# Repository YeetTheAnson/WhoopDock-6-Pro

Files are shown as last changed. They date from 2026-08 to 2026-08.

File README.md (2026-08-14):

# WhoopDock 6 Pro

## Introduction

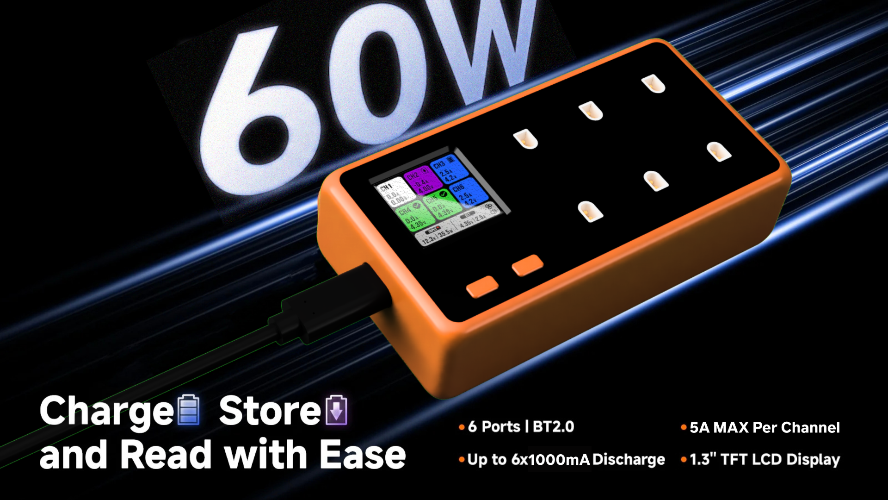
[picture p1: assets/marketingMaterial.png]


*Up to 130W when powered with VBUS pads

This is my custom BT2.0 battery charger! I started this project because I wanted a programmable 1S LiPo/LiHV multi channel charger that included discharging and storage mode. Commercial chargers like the hexachargers or whoopstor has all the mentioned features but it's limited and lack customizability.

This charger is designed primarily for tinywhoop FPV drone batteries that uses the BetaFPV BT2.0 connector, but its 5A charge current also allows it to be used with larger cylindrical cell batteries for long range drones.

| Feature | WhoopDock 6 Pro | BetaFPV Hexacharger | ViFly WhoopStor V3 |
| --- | --- | --- | --- |
| **Max Charge Current (Per Channel)** | **Up to 5A**  | 3.0A | 1.3A |
| **Max Discharge Current (Per Channel)** | **1.16A** | 0.4A | 0.3A |
| **Custom Discharge Current** | **Yes**  | No | No |
| **Target Voltage Control** | **Fully Customizable** | Presets Only | Presets Only |
| **Voltage Increments** | **16mV** | None (3.85V/4.2V/4.35V) | None (3.8V/3.85V/4.2V/4.35V) |
| **Current Increments** | **64mA** | 500mA | 100mA |
| **Big Colour Screen** | **Yes** | **Yes** | No |
| **Programmability** | **Yes** (Arduino compatible) | No (Closed source) | No (Closed source) |
| **WiFi & Bluetooth** | **Yes** | No | No |
| **Audio Feedback** | **Yes** | **Yes** | **Yes** |
| **Active Cooling** | **Yes** (Programmable fan curve) | **Yes** | **Yes** |
| **Reverse Polarity Protection** | **Yes** | No | **Yes** |

If you don't like how it works, you could always program it to replicate the behavior of your favorite charger.

### Advantages:

* **Current Delivery:** The WhoopDock is much more powerful compared to commercial chargers from BetaFPV and ViFly. With the BQ25890, you can charge large batteries up to 5A, or use the small 64mA interval to precisely control the charge current of small batteries. The 1.16A discharge rate means your large batteries will hit storage voltage way faster, and can be adjusted lower for smaller batteries.
* **Fine Control:** Instead of being forced to choose from specific presets, the 16mV step resolution allows you to charge different battery chemistries or set a custom charge termination voltage.
* **Connectivity:** Having Bluetooth and WiFi onboard allows you to monitor charge cycles from your phone, and receive push notifications when charging is complete.

### Drawbacks:
* **Max power:** While the WhoopDock 60W power is still more than the hexacharger's 24W, the pro version supports up to 78W. The 60W limit is due to the USB C specification, and it supports up to 130W if powered directly by bypassing USB connectors.
* **No PH2.0 connector:** This is intentional by design as PH2.0 is an inferior connector compared to BT2.0, and it only supports a continuous charge current of 2A.

---

## Hardware Specifications

* **MCU:** ESP32-S3-WROOM-1-N8
* **Charge Controller:** 6x TI BQ25890
* **I2C Multiplexer:** TCA9548A
* **PD Negotiation:** CH224K
* **Display:** 1.3" 240x240 ST7789 TFT
* **Power Supply:** XL1509-5.0E1 5V Buck Converter, 2x RT9193 3.3v LDO (One for ESP32 and another to power the display)
* **Active Cooling:** 5V 4010 blower fan and dual 60x20x10mm aluminum heatsinks
* **Protection:** AO4407A P Channel MOSFETs for battery reverse polarity insertion protection

Note: The BQ25890 has a maximum input voltage limit of 14V. The CH224K is configured to negotiate 12V for optimal performance. Do not bridge the 15V or 20V jumpers on the PD controller. Only use 2-3s batteries on the VBUS input pads.

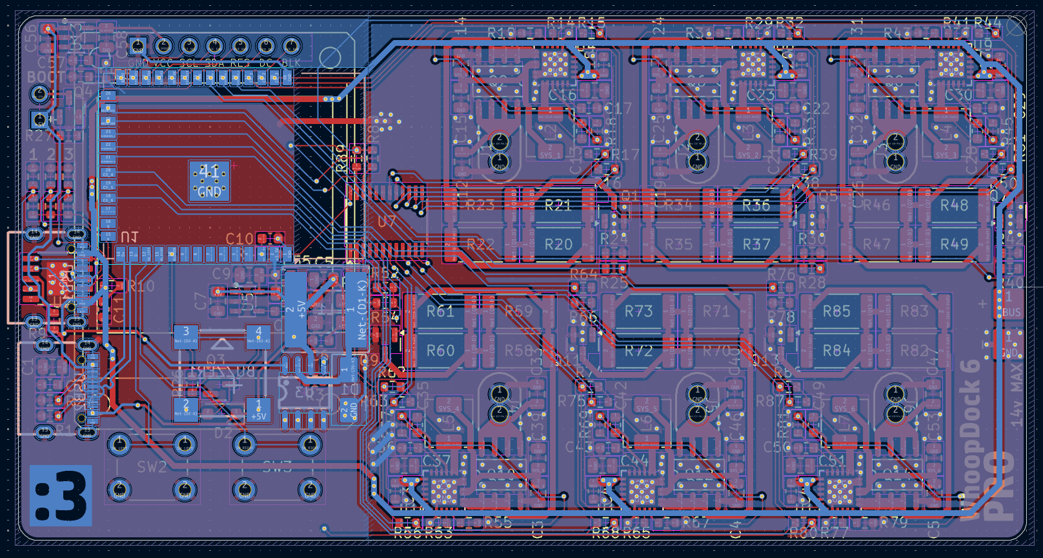
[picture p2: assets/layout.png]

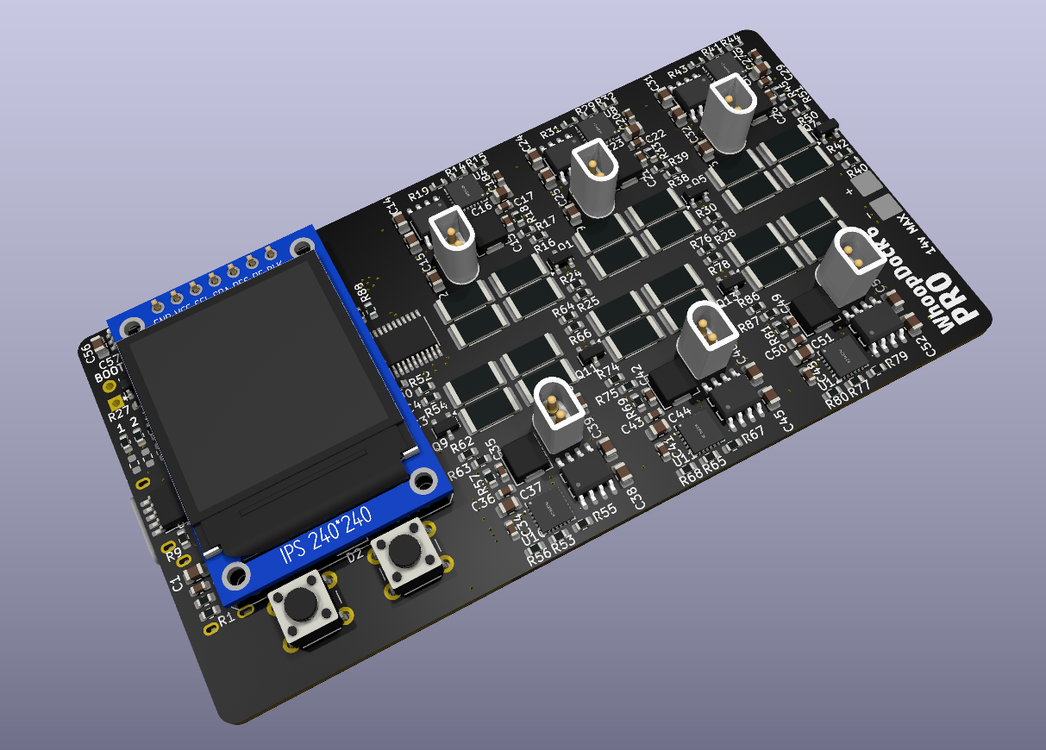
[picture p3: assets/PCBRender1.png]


---

> [!WARNING]
> **DO NOT USE THE OCTAL PSRAM VERSION OF THE ESP32S3.** The octal version uses GPIO35, 36 and 37 for memory which overlap with the GPIOs used in the charger. Use QUAD SPI versions otherwise the ESP32 will fail to boot.

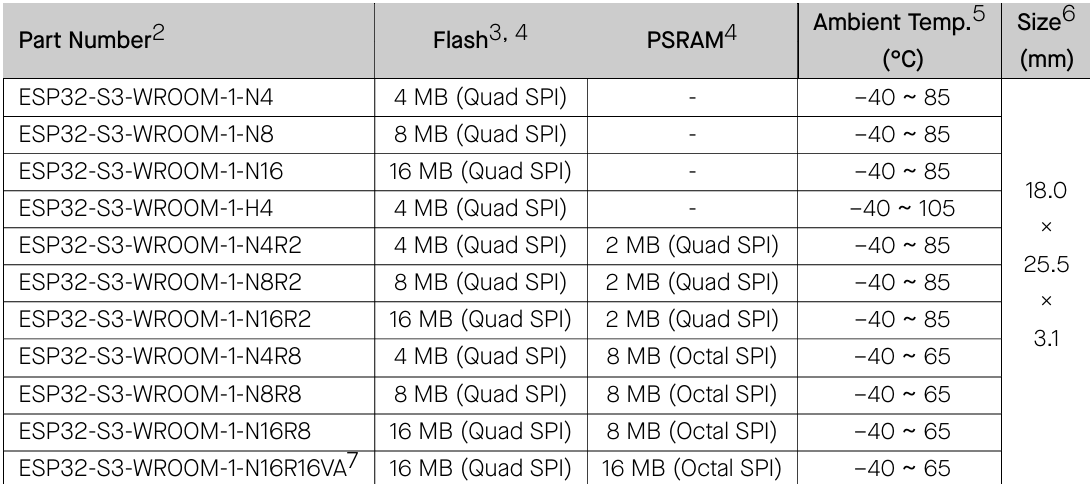
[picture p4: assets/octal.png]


## Ports and Interfaces

### External Connections

* **Main Power (Protruding USB C):** This is the primary power input and supports up to 12v 5A (60W)
* **Programming (Flush USB C):** Connected directly to the ESP32 USB data pins for programming. Cannot be accessed while inside the case.
* **Direct Power Pads:** Exposed solder pads on the PCB to bypass the USBC port entirely. Solder XT30 connectors here to bypass the power limit of USB C

### Pinout

| Component | Pin Name | ESP32S3 GPIO | Description |
| --- | --- | --- | --- |
| **TFT Display** | `SCL`| GPIO 35 | SPI Clock |
|  | `TFT_SDA`| GPIO 36 | SPI Data |
|  | `TFT_RES` | GPIO 37 | Display Reset |
|  | `TFT_DC` | GPIO 38 | Data / Command |
|  | `TFT_BLK` | GPIO 39 | Backlight Control |
| **I2C Bus** | `MAIN_SDA` | GPIO 47 | Main I2C Data (TCA9548A MUX) |
|  | `MAIN_SCL` | GPIO 48 | Main I2C Clock (TCA9548A MUX) |
| **User Interface** | `SW_LEFT` | GPIO 8 | Left Button (Active Low) |
|  | `SW_RIGHT` | GPIO 18 | Right Button (Active Low) |
|  | `BUZZER` | GPIO 17 | Passive Buzzer |
| **Cooling** | `FAN` | GPIO 40 | 4010 Fan PWM Power |

*Note: The CE pins are pulled high by 5.1k resistors.*

|Battery Channel | Charge Enable GPIO | Discharge PWM GPIO | TCA9548A MUX Port |
| --- | --- | --- | --- |
| **Channel 1** | GPIO 43 | GPIO 41 | Port 6 |
| **Channel 2** | GPIO 2 | GPIO 42 | Port 5 |
| **Channel 3** | GPIO 1 | GPIO 44 | Port 4 |
| **Channel 4** | GPIO 12 | GPIO 13 | Port 1 |
| **Channel 5** | GPIO 11 | GPIO 14 | Port 2 |
| **Channel 6** | GPIO 10 | GPIO 21 | Port 3 |



---

## Firmware Setup

The current firmware is for connection validation only, and isn't production ready yet. Your batteries WILL charge
### How to flash the firmware

1. **Connect to the Programming Port:** Plug a USBC cable into the flush USBC port (not the protruding power port).
2. **Open Arduino IDE:** Load `firmware/firmware.ino`.
3. **Select Board:** Choose "ESP32S3 Dev Module". Ensure "USB CDC On Boot" is enabled to view the serial monitor for debugging.
4. **Flash:** Click upload. The firmware will initialize the ST7789 display, ramp up and down the fan and buzzer, scans the I2C multiplexer ports and then reports the status of all BQ25890 to the serial monitor.

---

## Case Assembly

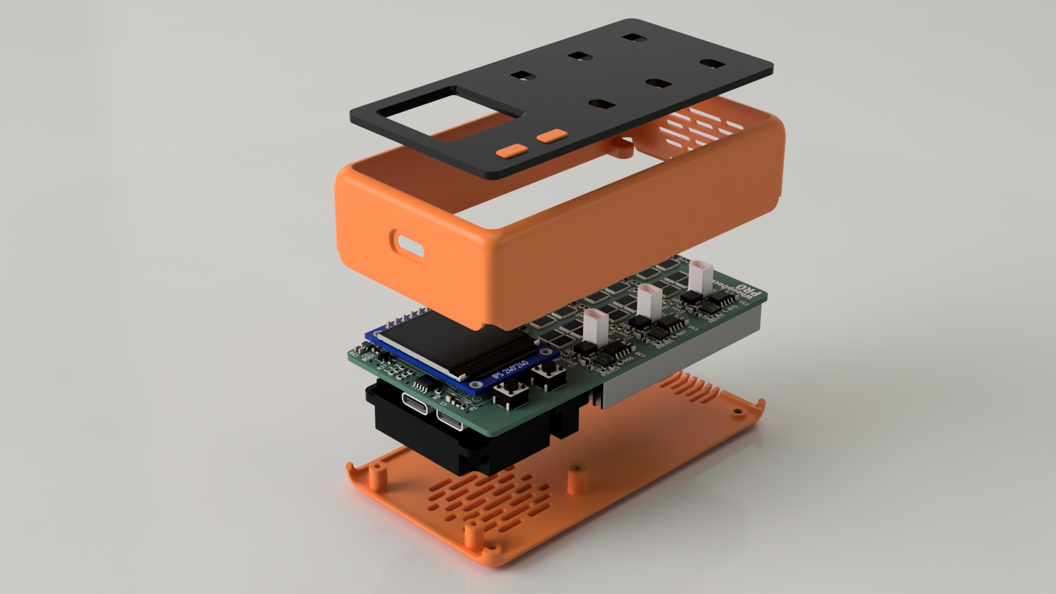
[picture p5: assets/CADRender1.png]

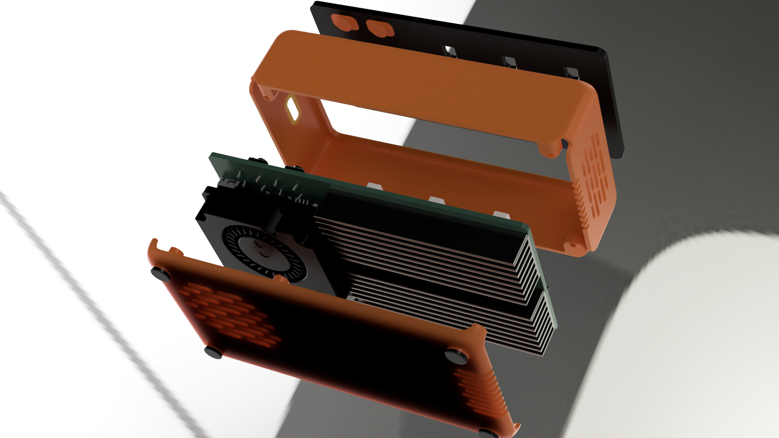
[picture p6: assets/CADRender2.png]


### 3D Printed Parts

All STL files for the case is in `/production/3dPrint/`.

* `bottomCase.stl`
* `topCase.stl`
* `Buttons.stl`
* `Feets.stl`

### Assembly

1. Create a solder bridge at CFG3 to set the Ch224K to 12V
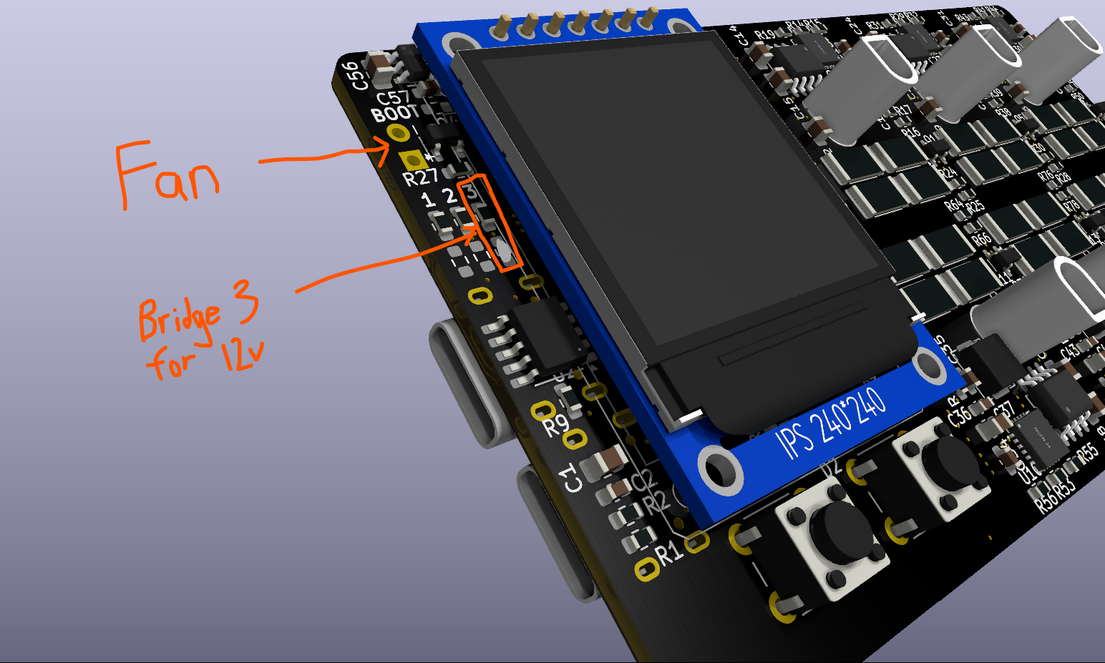
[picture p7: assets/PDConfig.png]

2. Trim the BetaFPV BT2.0 connector legs. Make a test fit **before** soldering to ensure it's not protruding.
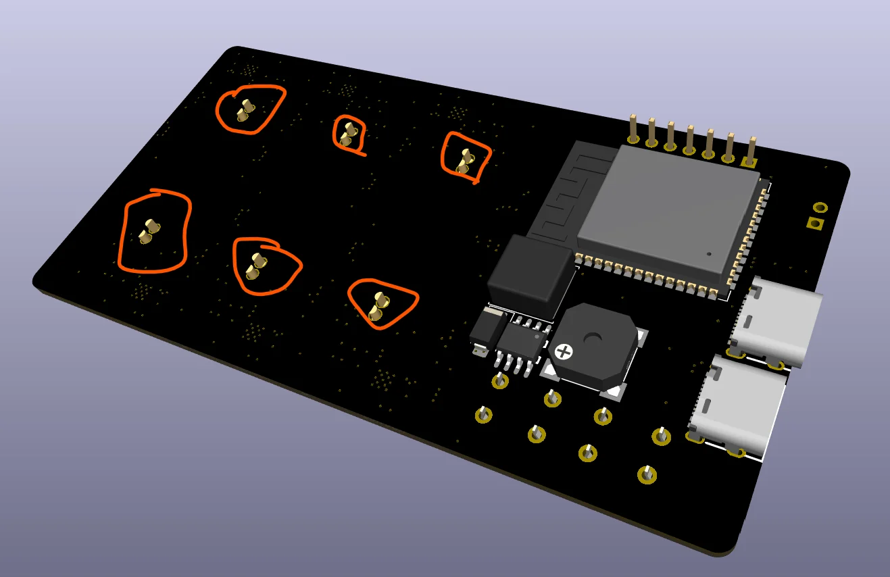
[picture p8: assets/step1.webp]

3. Place the 3D printed `Buttons.stl` into the holes on `topCase.stl`.
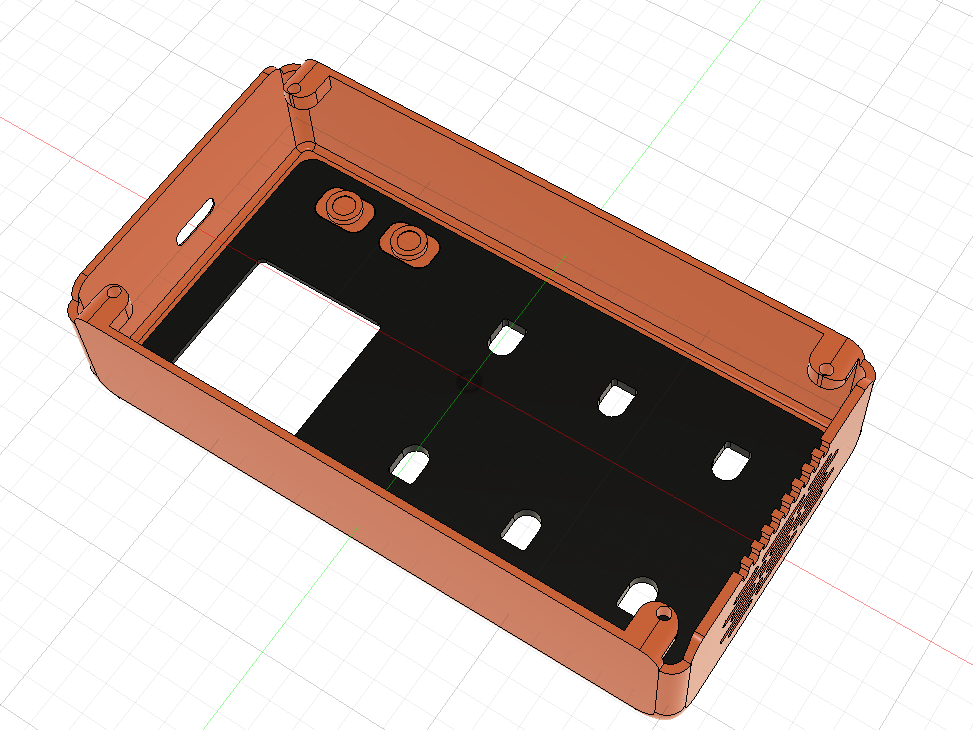
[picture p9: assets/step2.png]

4. Screw in the 4010 blower fan into the bottom case using 4x M2x6mm screws.
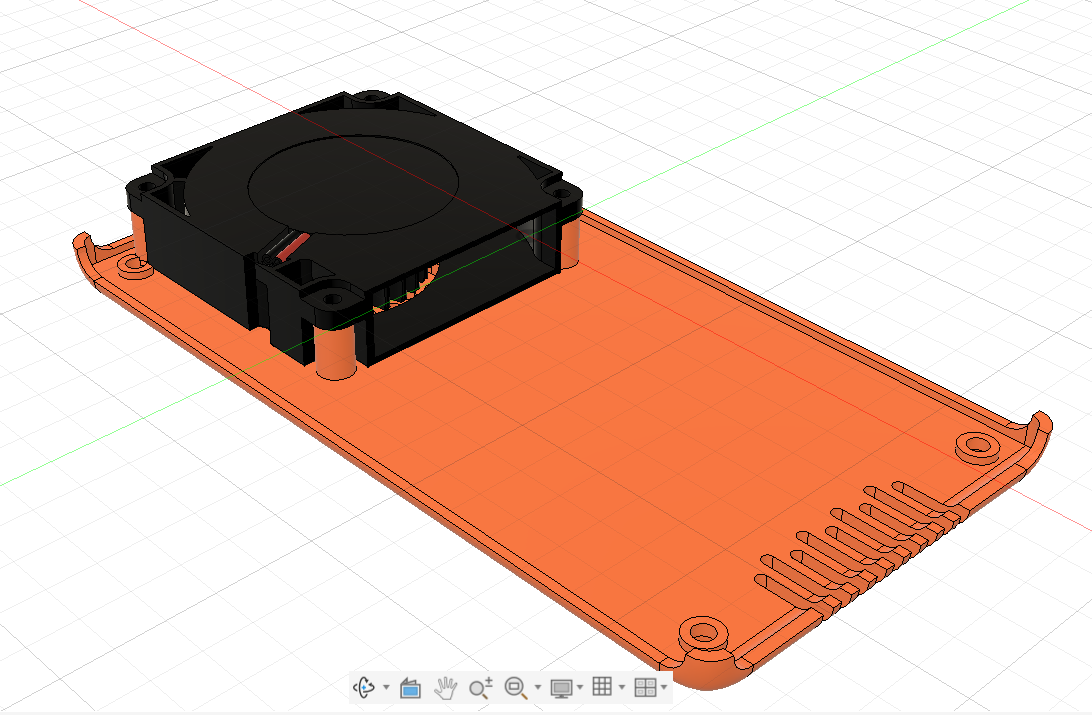
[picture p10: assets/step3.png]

5. Snap the PCB into the top case.
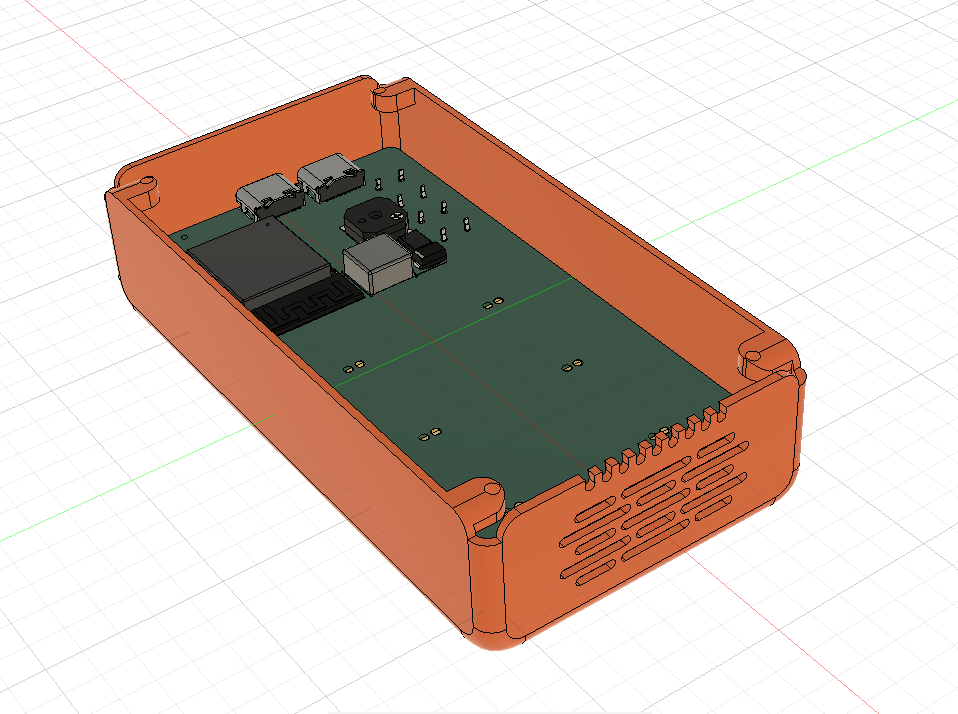
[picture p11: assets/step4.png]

6. Apply thermal adhesives on the two heatsink and attach to the PCB.
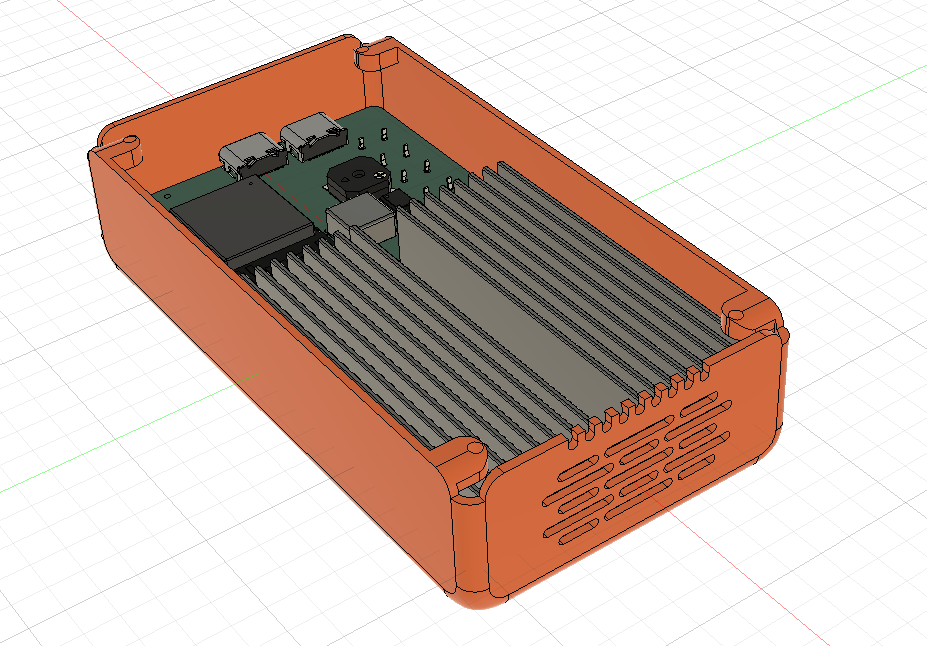
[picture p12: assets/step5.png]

7. Secure the bottom case onto the top case and screw in using 4x M2x6mm screws. Remember to solder the solder the fan wires before closing the case.
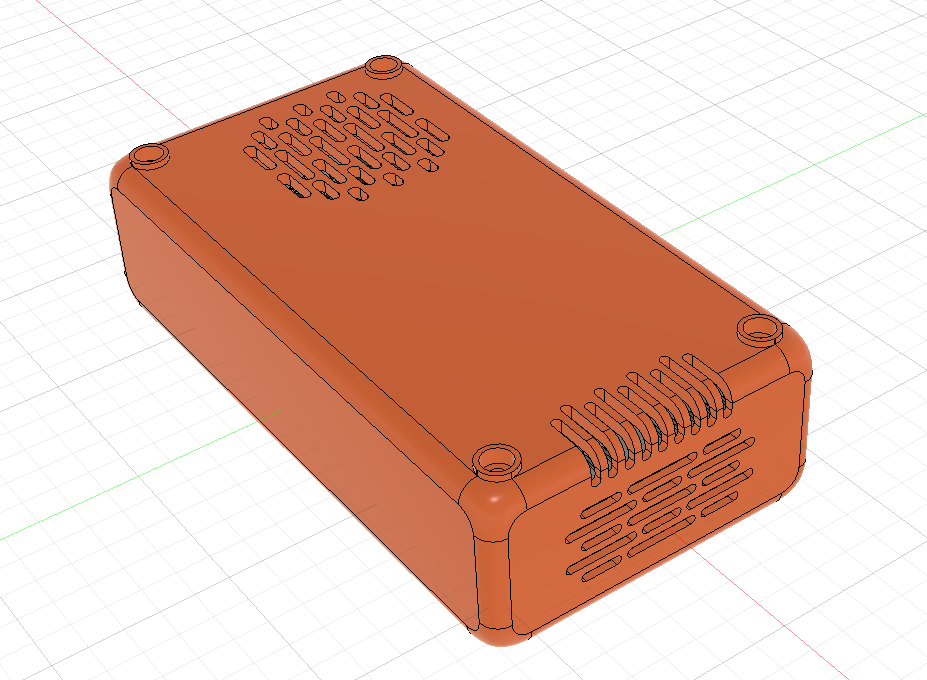
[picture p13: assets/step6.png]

8. Attach the TPU  `Feets.stl` to the bottom to cover the screws and prevent sliding. You may use glue to keep the feets in.
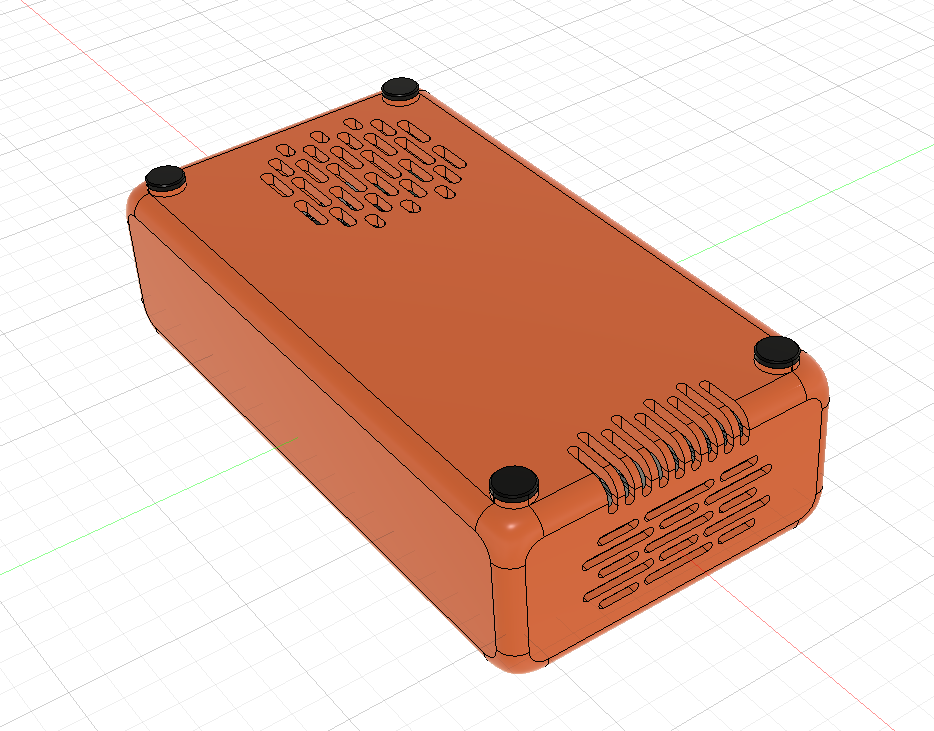
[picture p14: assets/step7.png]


---

## Bill of Material

Note: The prices in USD are converted as of 13 August 2026 and prices may fluctuate. Promo codes will be applied before checkout to bring the costs down. And yes, the costs of separate components are cheaper than JLCPCB assembly.

| Item Name | Link | Vendor | Quantity | Total Price (USD) |
| --- | --- | --- | --- | ---: |
| Heatsink 60x20x10mm | [Link](https://shopee.com.my/Heatsink-40x40x11-mm-Aluminium-Clear-Black-Gold-Anodized-i.6674515.812567757) | Shopee | 2 | 0.85 |
| MLT8530 Buzzer 5v | [Link](https://shopee.com.my/5Pcs-SMD-Magnetic-Piezo-Loudspeaker-Speaker-Buzzer-8630-1109-9045-9025-9018-5020-1230-9032-7525-8630-8540-Passive-9650-Active-i.1649836180.2754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) | Shopee | 1 | 1.45 |
| Capacitor 100nF 50v (0603) | [Link](https://shopee.com.my/100pcs-0603-1608-SMD-Chip-Multilayer-Ceramic-Capacitor-0.1pF-22uF-10pF-22pF-100pF-1nF-10nF-15nF-100nF-0.1uF-1uF-2.2uF-4.7uF-10-i.1649836180.275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) | Shopee | 1 | 0.90 |
| Capacitor 10nF 50v (0603) | [Link](https://shopee.com.my/100pcs-0603-1608-SMD-Chip-Multilayer-Ceramic-Capacitor-0.1pF-22uF-10pF-22pF-100pF-1nF-10nF-15nF-100nF-0.1uF-1uF-2.2uF-4.7uF-10-i.1649836180.275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) | Shopee | 1 | 0.98 |
| Capacitor 1uF 25v (0603) | [Link](https://shopee.com.my/100pcs-0603-1608-SMD-Chip-Multilayer-Ceramic-Capacitor-0.1pF-22uF-10pF-22pF-100pF-1nF-10nF-15nF-100nF-0.1uF-1uF-2.2uF-4.7uF-10-i.1649836180.275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) | Shopee | 1 | 0.91 |
| Capacitor 47nF 50v (0603) | [Link](https://shopee.com.my/100pcs-0603-1608-SMD-Chip-Multilayer-Ceramic-Capacitor-0.1pF-22uF-10pF-22pF-100pF-1nF-10nF-15nF-100nF-0.1uF-1uF-2.2uF-4.7uF-10-i.1649836180.275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) | Shopee | 1 | 0.94 |
| Capacitor 4.7uF 16v (0603) | [Link](https://shopee.com.my/100pcs-0603-1608-SMD-Chip-Multilayer-Ceramic-Capacitor-0.1pF-22uF-10pF-22pF-100pF-1nF-10nF-15nF-100nF-0.1uF-1uF-2.2uF-4.7uF-10-i.1649836180.275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) | Shopee | 1 | 1.50 |
| Capacitor 10uF 25v (0805) | [Link](https://shopee.com.my/100pcs-0805-SMD-Chip-Multilayer-Ceramic-Capacitor-0.5pF-47uF-10pF-22pF-100pF-1nF-10nF-100nF-0.1uF-1uF-2.2uF-4.7uF-10uF-22uF-i.1649836180.568640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) | Shopee | 1 | 3.86 |
| Tantalum Capacitor 33uF 10v (A) | [Link](https://shopee.com.my/10Pcs-3216A-SMD-Tantalum-Capacitor-100-220-330-470-1UF-2.2UF-3.3UF-4.7UF-6.8UF-22UF-33UF-47UF-100UF-4V-6.3V-10V-16V-20V-25V-35V-i.1649836180.55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) | Shopee | 1 | 1.90 |
| Diode SS14 | [Link](https://shopee.com.my/10-Pieces-SB1045L-SB10100L-SL1045-B240A-SS12-SS14-SS16-SS24-SS26-SS34-SS36-SS54-SS56-SS110-SS210-SS2200-DSK16-DSK24-DSK26-i.1649836180.47204908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) | Shopee | 1 | 0.82 |
| Inductor 1uH (0420) | [Link](https://shopee.com.my/5PCS-SMD-Molding-Power-Inductors-0420-0520-0530-0630-0650-1040-1265-1R0-2R2-6R8-1UH-2.2-3.3-4.7-6.8-33-100UH-2.2UH-Inductance-i.1649836180.4595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) | Shopee | 2 | 2.10 |
| Resistor 5.1k (0603) | [Link](https://shopee.com.my/200pcs-0603-5-SMD-Resistor-0R-~-10M-1-10W-10-100-150-220-330-470-ohm-1K-2.2K-4.7K-10K-100K-1M-1R-10R-100R-150R-220R-330R-470R-i.1649836180.5785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) | Shopee | 1 | 0.75 |
| Resistor 10k (0603) | [Link](https://shopee.com.my/200pcs-0603-5-SMD-Resistor-0R-~-10M-1-10W-10-100-150-220-330-470-ohm-1K-2.2K-4.7K-10K-100K-1M-1R-10R-100R-150R-220R-330R-470R-i.1649836180.5785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) | Shopee | 1 | 0.75 |
| Resistor 1k (0603) | [Link](https://shopee.com.my/200pcs-0603-5-SMD-Resistor-0R-~-10M-1-10W-10-100-150-220-330-470-ohm-1K-2.2K-4.7K-10K-100K-1M-1R-10R-100R-150R-220R-330R-470R-i.1649836180.5785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) | Shopee | 1 | 0.75 |
| Resistor 100 (0603) | [Link](https://shopee.com.my/200pcs-0603-5-SMD-Resistor-0R-~-10M-1-10W-10-100-150-220-330-470-ohm-1K-2.2K-4.7K-10K-100K-1M-1R-10R-100R-150R-220R-330R-470R-i.1649836180.5785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) | Shopee | 1 | 0.75 |
| ESP32-S3-WROOM-1-N8 | [Link](https://shopee.com.my/1Pcs-ESP32-S3-ESP32-S3-WROOM-1-1U-ESP32-S3-MINI-1U-4MB-8MB-16MB-N4-N4R2-N4R8-N8-N8R2-N8R8-N16-N16R2-N16R8-WiFi-Ble-5.0-Module-i.1649836180.4317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) | Shopee | 1 | 6.02 |
| USBC Connector | [Link](https://shopee.com.my/5Pcs-USB-Type-C-3.1-2-6-16-24-Pin-Connector-Female-Jack-Charging-Port-SMD-SMT-PCB-Solder-DIY-Repair-USB-C-Type-C-Socket-i.1649836180.4550207893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) | Shopee | 1 | 0.85 |
| Resistor 15 (2512) | [Link](https://shopee.com.my/(20pcs)-2512-SMD-Resistor-0.1R~910R-5-0.2R-0.15R-0.25R-0.22R-0.47R-0R-1R-1.5R-5.1R-2.2R-4.7R-10R-22R-47R-50R-100R-220R-330R-470R-Ohm-Resistance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) | Shopee | 2 | 1.24 |
| BetaFPV BT2.0 Connector | [Link](https://shopee.com.my/1-Pair-BETAFPV-BT2.0-Connector-BTC2.0-i.92575144.7717088511) | Shopee | 6 | 7.34 |
| N Channel Mosfet AO3400A | [Link](https://shopee.com.my/50pcs-AO3400-SOT23-AO3400A-SOT-23-A09T-SOT-AO3401-AO3402-AO3404-AO3406-AO3407-AO3415-AO3416-SMD-Field-Effect-Management-i.1135937572.2425765112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) | Shopee | 1 | 0.85 |
| P Channel Mosfet AO4007A | [Link](https://shopee.com.my/10pcs-lot-AO4407AL-AO4407A-AO4407-4407A-4407-SOP8-30V-12A-P-Channel-MOSFET-In-Stock-i.304553259.7152107243) | Shopee | 1 | 0.92 |
| XL1509-5.0E1 | [Link](https://shopee.com.my/10-PCS-XL1509-ADJE1-XL1509-ADJ-XL1509-5.0E1-XL1509-5.0-XL1509-3.3E1-XL1509-3.3-XL1509-SOP-8-In-Stock-i.304553259.23988849871) | Shopee | 1 | 1.65 |
| BQ25890 | [Link](https://shopee.com.my/5PCS-BQ25601-BQ25890-QFN-BQ25890H-BQ25896-BQ25892RTWR-BQ-series-charging-ics-IC-i.1592750725.44459693293) | Shopee | 2 | 10.00 |
| I2C Multiplexer TCA9548 | [Link](https://shopee.com.my/CJMCU-9548-TCA9548-TCA9548A-1-to-8-I2C-8-way-multi-channel-Expansion-Board-IIC-Module-i.927139050.23724940668) | Shopee | 1 | 0.84 |
| 1.3" TFT Display | [Link](https://shopee.com.my/TFT-Display-0.96-1.3-1.44-Inch-IPS-7P-SPI-HD-65K-Full-Color-LCD-Module-ST7735-Drive-IC-80*160-(Not-OLED)-For-Arduino-i.509537957.11442443894) | Shopee | 1 | 2.72 |
| PCB |  | JLCPCB | 1 | 2.00 |
| SPX Express Shipping |  | Shopee | 9 | 11.45 |
| PCB Shipping |  | JLCPCB | 1 | 1.50 |
| **GRAND TOTAL** |  |  |  | **66.59** |

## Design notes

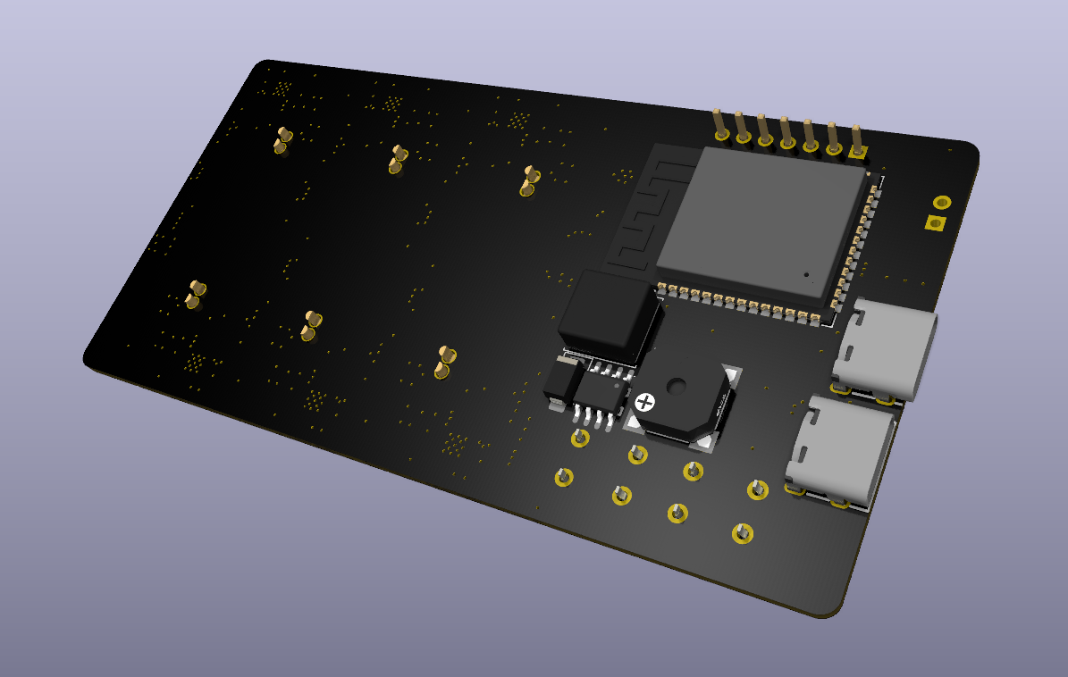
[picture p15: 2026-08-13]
assets/PCBRender2.png

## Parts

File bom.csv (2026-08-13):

Item Name | Link | Vendor | Quantity | Total Price (USD)
Heatsink 60x20x10mm | https://shopee.com.my/Heatsink-40x40x11-mm-Aluminium-Clear-Black-Gold-Anodized-i.6674515.812567757 | Shopee | 2 | 0.85
MLT8530 Buzzer 5v | https://shopee.com.my/5Pcs-SMD-Magnetic-Piezo-Loudspeaker-Speaker-Buzzer-8630-1109-9045-9025-9018-5020-1230-9032-7525-8630-8540-Passive-9650-Active-i.16498361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 | Shopee | 1 | 1.45
Capacitor 100nF 50v (0603) | https://shopee.com.my/100pcs-0603-1608-SMD-Chip-Multilayer-Ceramic-Capacitor-0.1pF-22uF-10pF-22pF-100pF-1nF-10nF-15nF-100nF-0.1uF-1uF-2.2uF-4.7uF-10-i.1649836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 | Shopee | 1 | 0.90
Capacitor 10nF 50v (0603) | https://shopee.com.my/100pcs-0603-1608-SMD-Chip-Multilayer-Ceramic-Capacitor-0.1pF-22uF-10pF-22pF-100pF-1nF-10nF-15nF-100nF-0.1uF-1uF-2.2uF-4.7uF-10-i.1649836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 | Shopee | 1 | 0.98
Capacitor 1uF 25v (0603) | https://shopee.com.my/100pcs-0603-1608-SMD-Chip-Multilayer-Ceramic-Capacitor-0.1pF-22uF-10pF-22pF-100pF-1nF-10nF-15nF-100nF-0.1uF-1uF-2.2uF-4.7uF-10-i.1649836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 | Shopee | 1 | 0.91
Capacitor 47nF 50v (0603) | https://shopee.com.my/100pcs-0603-1608-SMD-Chip-Multilayer-Ceramic-Capacitor-0.1pF-22uF-10pF-22pF-100pF-1nF-10nF-15nF-100nF-0.1uF-1uF-2.2uF-4.7uF-10-i.1649836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 | Shopee | 1 | 0.94
Capacitor 4.7uF 16v (0603) | https://shopee.com.my/100pcs-0603-1608-SMD-Chip-Multilayer-Ceramic-Capacitor-0.1pF-22uF-10pF-22pF-100pF-1nF-10nF-15nF-100nF-0.1uF-1uF-2.2uF-4.7uF-10-i.1649836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 | Shopee | 1 | 1.50
Capacitor 10uF 25v (0805) | https://shopee.com.my/100pcs-0805-SMD-Chip-Multilayer-Ceramic-Capacitor-0.5pF-47uF-10pF-22pF-100pF-1nF-10nF-100nF-0.1uF-1uF-2.2uF-4.7uF-10uF-22uF-i.1649836180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 | Shopee | 1 | 3.86
Tantalum Capacitor 33uF 10v (A) | https://shopee.com.my/10Pcs-3216A-SMD-Tantalum-Capacitor-100-220-330-470-1UF-2.2UF-3.3UF-4.7UF-6.8UF-22UF-33UF-47UF-100UF-4V-6.3V-10V-16V-20V-25V-35V-i.164983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 | Shopee | 1 | 1.90
Diode SS14 | https://shopee.com.my/10-Pieces-SB1045L-SB10100L-SL1045-B240A-SS12-SS14-SS16-SS24-SS26-SS34-SS36-SS54-SS56-SS110-SS210-SS2200-DSK16-DSK24-DSK26-i.1649836180.4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 | Shopee | 1 | 0.82
Inductor 1uH (0420) | https://shopee.com.my/5PCS-SMD-Molding-Power-Inductors-0420-0520-0530-0630-0650-1040-1265-1R0-2R2-6R8-1UH-2.2-3.3-4.7-6.8-33-100UH-2.2UH-Inductance-i.16498361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 | Shopee | 2 | 2.10
Resistor 5.1k (0603) | https://shopee.com.my/200pcs-0603-5-SMD-Resistor-0R-~-10M-1-10W-10-100-150-220-330-470-ohm-1K-2.2K-4.7K-10K-100K-1M-1R-10R-100R-150R-220R-330R-470R-i.16498361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 | Shopee | 1 | 0.75
Resistor 10k (0603) | https://shopee.com.my/200pcs-0603-5-SMD-Resistor-0R-~-10M-1-10W-10-100-150-220-330-470-ohm-1K-2.2K-4.7K-10K-100K-1M-1R-10R-100R-150R-220R-330R-470R-i.16498361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 | Shopee | 1 | 0.75
Resistor 1k (0603) | https://shopee.com.my/200pcs-0603-5-SMD-Resistor-0R-~-10M-1-10W-10-100-150-220-330-470-ohm-1K-2.2K-4.7K-10K-100K-1M-1R-10R-100R-150R-220R-330R-470R-i.16498361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 | Shopee | 1 | 0.75
Resistor 100 (0603) | https://shopee.com.my/200pcs-0603-5-SMD-Resistor-0R-~-10M-1-10W-10-100-150-220-330-470-ohm-1K-2.2K-4.7K-10K-100K-1M-1R-10R-100R-150R-220R-330R-470R-i.16498361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 | Shopee | 1 | 0.75
ESP32-S3-WROOM-1-N8 | https://shopee.com.my/1Pcs-ESP32-S3-ESP32-S3-WROOM-1-1U-ESP32-S3-MINI-1U-4MB-8MB-16MB-N4-N4R2-N4R8-N8-N8R2-N8R8-N16-N16R2-N16R8-WiFi-Ble-5.0-Module-i.16498361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 | Shopee | 1 | 6.02
USBC Connector | https://shopee.com.my/5Pcs-USB-Type-C-3.1-2-6-16-24-Pin-Connector-Female-Jack-Charging-Port-SMD-SMT-PCB-Solder-DIY-Repair-USB-C-Type-C-Socket-i.1649836180.455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 | Shopee | 1 | 0.85
Resistor 15 (2512) | https://shopee.com.my/(20pcs)-2512-SMD-Resistor-0.1R~910R-5-0.2R-0.15R-0.25R-0.22R-0.47R-0R-1R-1.5R-5.1R-2.2R-4.7R-10R-22R-47R-50R-100R-220R-330R-470R-Ohm-Res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 | Shopee | 2 | 1.24
BetaFPV BT2.0 Connector | https://shopee.com.my/1-Pair-BETAFPV-BT2.0-Connector-BTC2.0-i.92575144.7717088511 | Shopee | 6 | 7.34
N Channel Mosfet AO3400A | https://shopee.com.my/50pcs-AO3400-SOT23-AO3400A-SOT-23-A09T-SOT-AO3401-AO3402-AO3404-AO3406-AO3407-AO3415-AO3416-SMD-Field-Effect-Management-i.1135937572.242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 | Shopee | 1 | 0.85
P Channel Mosfet AO4007A | https://shopee.com.my/10pcs-lot-AO4407AL-AO4407A-AO4407-4407A-4407-SOP8-30V-12A-P-Channel-MOSFET-In-Stock-i.304553259.7152107243 | Shopee | 1 | 0.92
XL1509-5.0E1 | https://shopee.com.my/10-PCS-XL1509-ADJE1-XL1509-ADJ-XL1509-5.0E1-XL1509-5.0-XL1509-3.3E1-XL1509-3.3-XL1509-SOP-8-In-Stock-i.304553259.23988849871 | Shopee | 1 | 1.65
BQ25890 | https://shopee.com.my/5PCS-BQ25601-BQ25890-QFN-BQ25890H-BQ25896-BQ25892RTWR-BQ-series-charging-ics-IC-i.1592750725.44459693293 | Shopee | 2 | 10.00
I2C Multiplexer TCA9548 | https://shopee.com.my/CJMCU-9548-TCA9548-TCA9548A-1-to-8-I2C-8-way-multi-channel-Expansion-Board-IIC-Module-i.927139050.23724940668 | Shopee | 1 | 0.84
1.3" TFT Display | https://shopee.com.my/TFT-Display-0.96-1.3-1.44-Inch-IPS-7P-SPI-HD-65K-Full-Color-LCD-Module-ST7735-Drive-IC-80*160-(Not-OLED)-For-Arduino-i.509537957.1144244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 | Shopee | 1 | 2.72
PCB |  | JLCPCB | 1 | 2.00
SPX Express Shipping |  | Shopee | 9 | 11.45
PCB Shipping |  | JLCPCB | 1 | 1.50
GRAND TOTAL |  |  |  | 66.59

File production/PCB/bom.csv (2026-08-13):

Designator | Footprint | Quantity | Value | LCSC Part #
BUZZER1 | BUZ-SMD_4P-L8.5-W8.5-P8.50-BR | 1 | MLT-8530 | C94599
C1, C12, C14, C15, C16, C19, C23, C24, C25, C26, C30, C31, C32, C33, C37, C38, C39, C40, C44, C45, C46, C47, C5, C51, C52, C53, C54, C56, C58, C7, C9 | 0805 | 31 | 10uF | C440198
C10, C11, C18, C20, C27, C34, C41, C48 | 0603 | 8 | 1uF | C15849
C13, C21, C28, C35, C42, C49 | 0603 | 6 | 47nF | C1622
C17, C22, C29, C36, C43, C50 | 0603 | 6 | 4.7uF | C19666
C2, C55, C6 | 0603 | 3 | 0.1uF | C14663
C3, C4 | CP_EIA-3216-18_Kemet-A | 2 | 100uF | C561794
C57, C8 | 0603 | 2 | 10nF | C57112
D1 | D_SMA | 1 | SS14 | C2480
D2 | D_SOD-123F | 1 | 1N4148W | C108804
J1, J2, J3, J4, J5, J6 | BetaFPV BT2.0 | 6 | BetaFPV_BT2.0
L1 | L_Sunlord_SWPA8040S | 1 | 68uH | C2894721
L2, L3, L4, L5, L6, L7 | L_APV_APH0420 | 6 | 1.5uH | C167205
M1 | Fan | 1 | Fan
Q1, Q11, Q13, Q3, Q4, Q5, Q7, Q9 | SOT-23 | 8 | AO3400A | C20917
Q10, Q12, Q14, Q2, Q6, Q8 | SOIC-8_L4.9-W3.9-P1.27-LS6.0-BL | 6 | AO4407A | C16072
R1, R15, R16, R17, R2, R24, R30, R32, R38, R39, R42, R44, R50, R51, R54, R56, R62, R63, R66, R68, R74, R75, R78, R80, R86, R87, R88, R89, R90 | 0603 | 29 | 5.1k | C23186
R10 | 0603 | 1 | 1k | C21190
R11, R12, R13, R18, R19, R3, R31, R33, R4, R43, R45, R5, R55, R57, R67, R69, R79, R81, R9 | 0603 | 19 | 10k | C25804
R14, R25, R26, R27, R28, R29, R40, R41, R52, R53, R64, R65, R76, R77 | 0603 | 14 | 100 | C22775
R20, R21, R22, R23, R34, R35, R36, R37, R46, R47, R48, R49, R58, R59, R60, R61, R70, R71, R72, R73, R82, R83, R84, R85 | 2512 | 24 | 15 | C20087
R6, R7, R8, R91 | 0603 | 4 | 0
SW2, SW3 | SW_PUSH_6mm_H5mm | 2 | SW_Push | C2837531
U1 | ESP32-S3-WROOM-1 | 1 | ESP32-S3-WROOM-1 | C2913198
U10, U11, U12, U4, U8, U9 | WQFN-24_L4.0-W4.0-P0.50-BL-EP | 6 | BQ25890_1 | C130451
U13, U5 | SOT-23-5_L3.0-W1.7-P0.95-LS2.8-BL | 2 | RT9193-33GB | C15651
U2 | SSOP-10-1EP_3.9x4.9mm_P1mm_EP2.1x3.3mm | 1 | CH224K | C970725
U3 | SOIC-8_L5.0-W4.0-P1.27-LS6.0-BL | 1 | XL1509-5.0E1 | C61063
U6 | 1.3 TFT | 1 | ~
U7 | TSSOP-24_4.4x7.8mm_P0.65mm | 1 | TCA9548APWR | C130026
USB1, USB2 | USB-C-SMD_TYPE-C-6PIN-2MD-073 | 2 | TYPE-C 16PIN 2MD(073) | C2765186

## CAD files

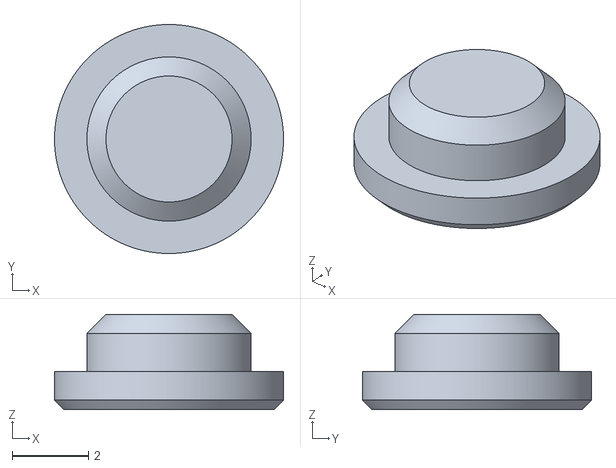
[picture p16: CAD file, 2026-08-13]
production/3dPrint/Feets.stl
6.00 x 6.00 x 2.50

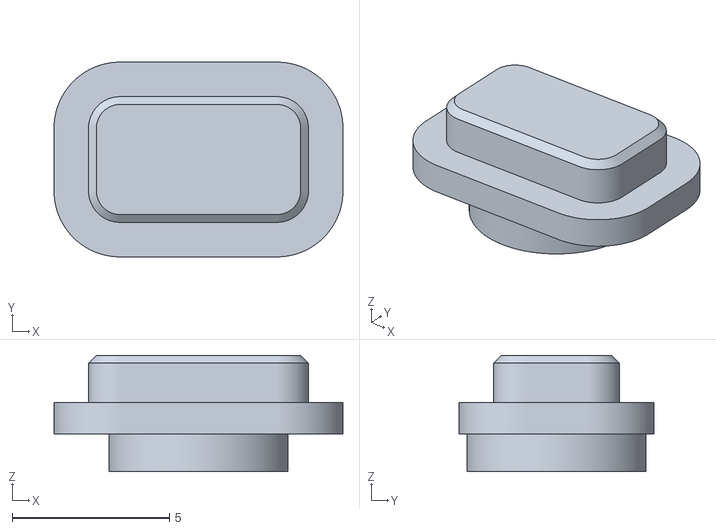
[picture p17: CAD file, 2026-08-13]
production/3dPrint/Buttons.stl
9.20 x 6.20 x 3.70

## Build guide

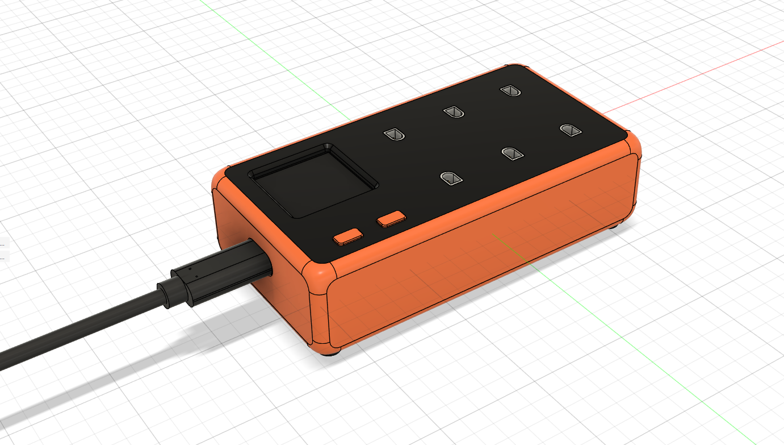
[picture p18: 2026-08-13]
assets/CADAssembled.png

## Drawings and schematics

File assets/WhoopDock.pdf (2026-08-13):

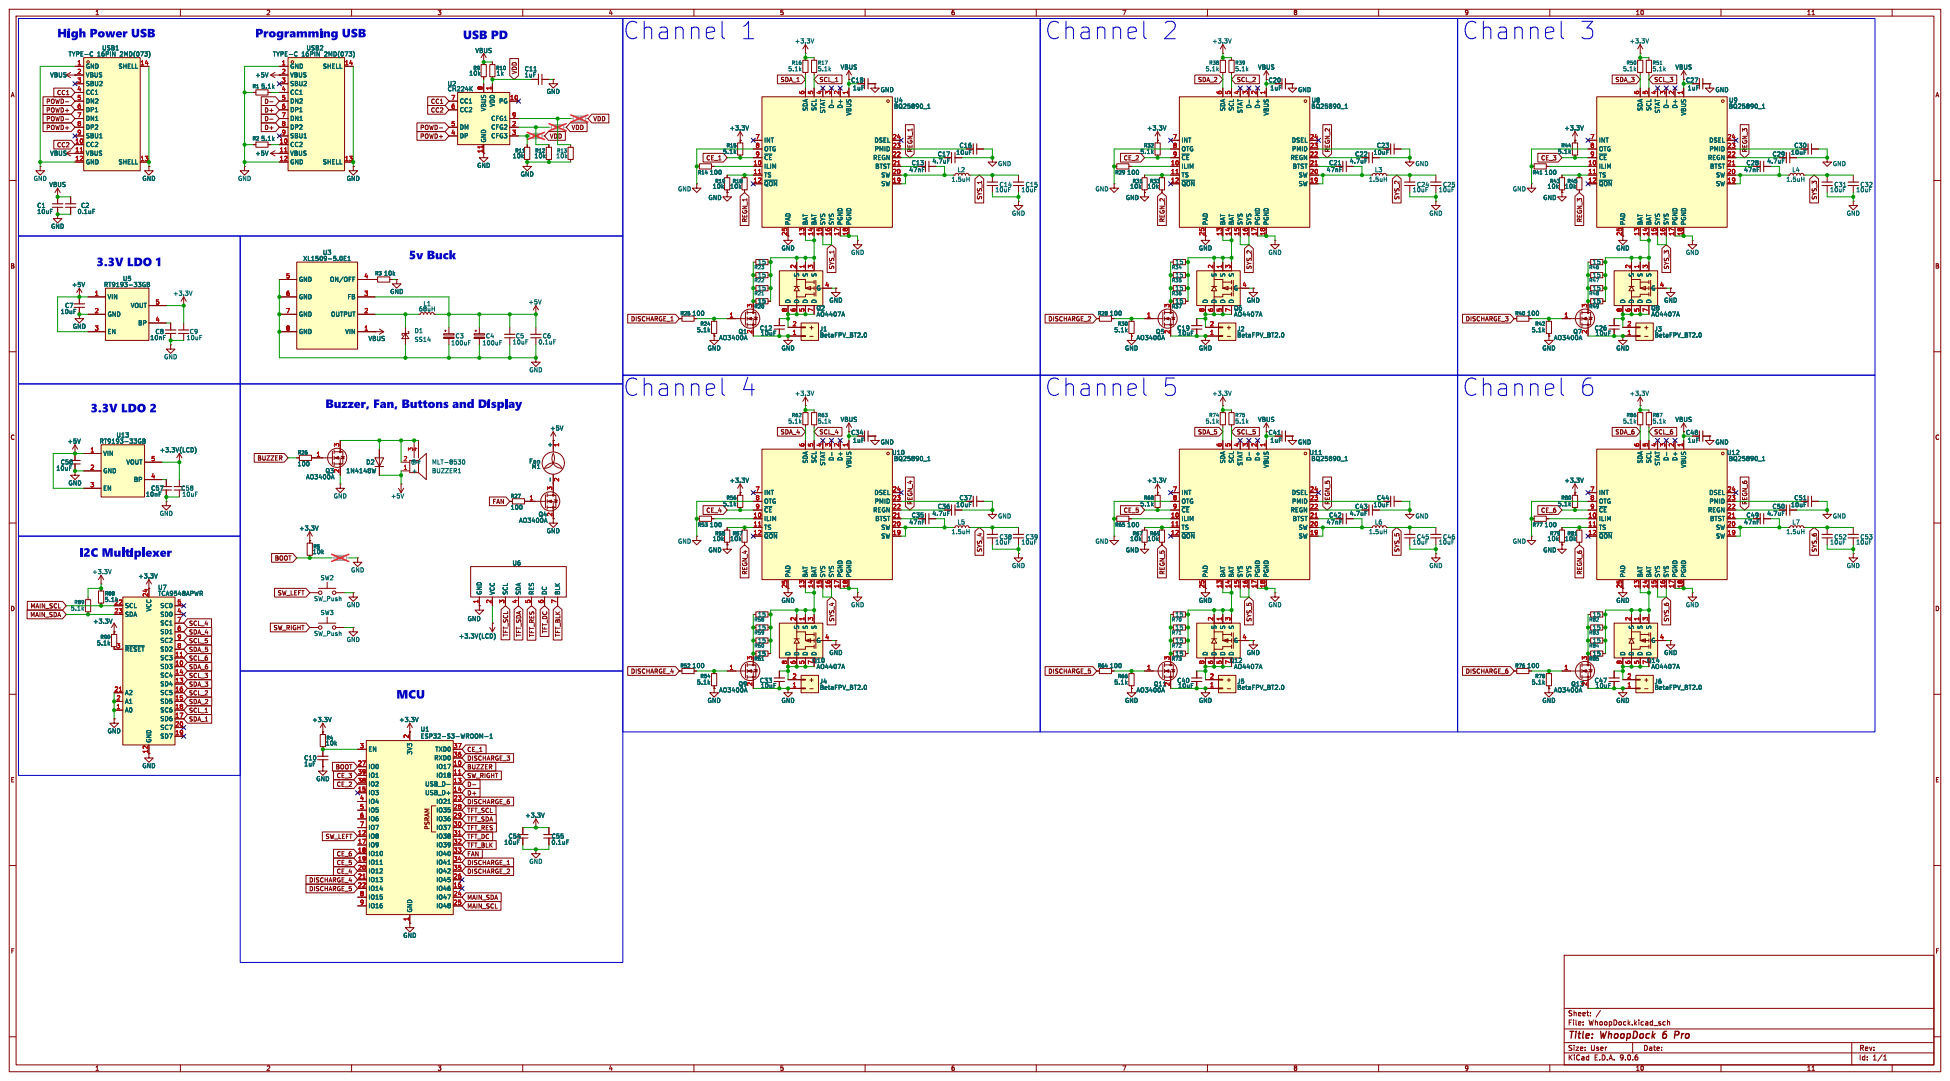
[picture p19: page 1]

POWD+ CC1 POWD- POWD+ CC2 POWD-

6 DSEL 24 INT 7 PMID 23 OTG 8 REGN 22 ~{CE} 9 BTST 21 ILIM 10 SW 20 TS 11 SW 19 ~{QON} 12 PGND 18 PGND 17 SYS 16 SYS 15 BAT 14 BAT 13 PAD 25 U4 BQ25890_1 GND

6 DSEL 24 INT 7 PMID 23 OTG 8 REGN 22 ~{CE} 9 BTST 21 ILIM 10 SW 20 TS 11 SW 19 ~{QON} 12 PGND 18 PGND 17 SYS 16 SYS 15 BAT 14 BAT 13 PAD 25 GND

Buzzer, Fan, Buttons and Display

6 DSEL 24 INT 7 PMID 23 OTG 8 REGN 22 ~{CE} 9 BTST 21 ILIM 10 SW 20 TS 11 SW 19 ~{QON} 12 PGND 18 PGND 17 SYS 16 SYS 15 BAT 14 BAT 13 PAD 25 U10 BQ25890_1

6 DSEL 24 INT 7 PMID 23 OTG 8 REGN 22 ~{CE} 9 BTST 21 ILIM 10 SW 20 TS 11 SW 19 ~{QON} 12 PGND 18 PGND 17 SYS 16 SYS 15 BAT 14 BAT 13 PAD 25 Q10AO4407A G

File: WhoopDock.kicad_sch Sheet: /
Id: 1/1 Title: WhoopDock 6 Pro

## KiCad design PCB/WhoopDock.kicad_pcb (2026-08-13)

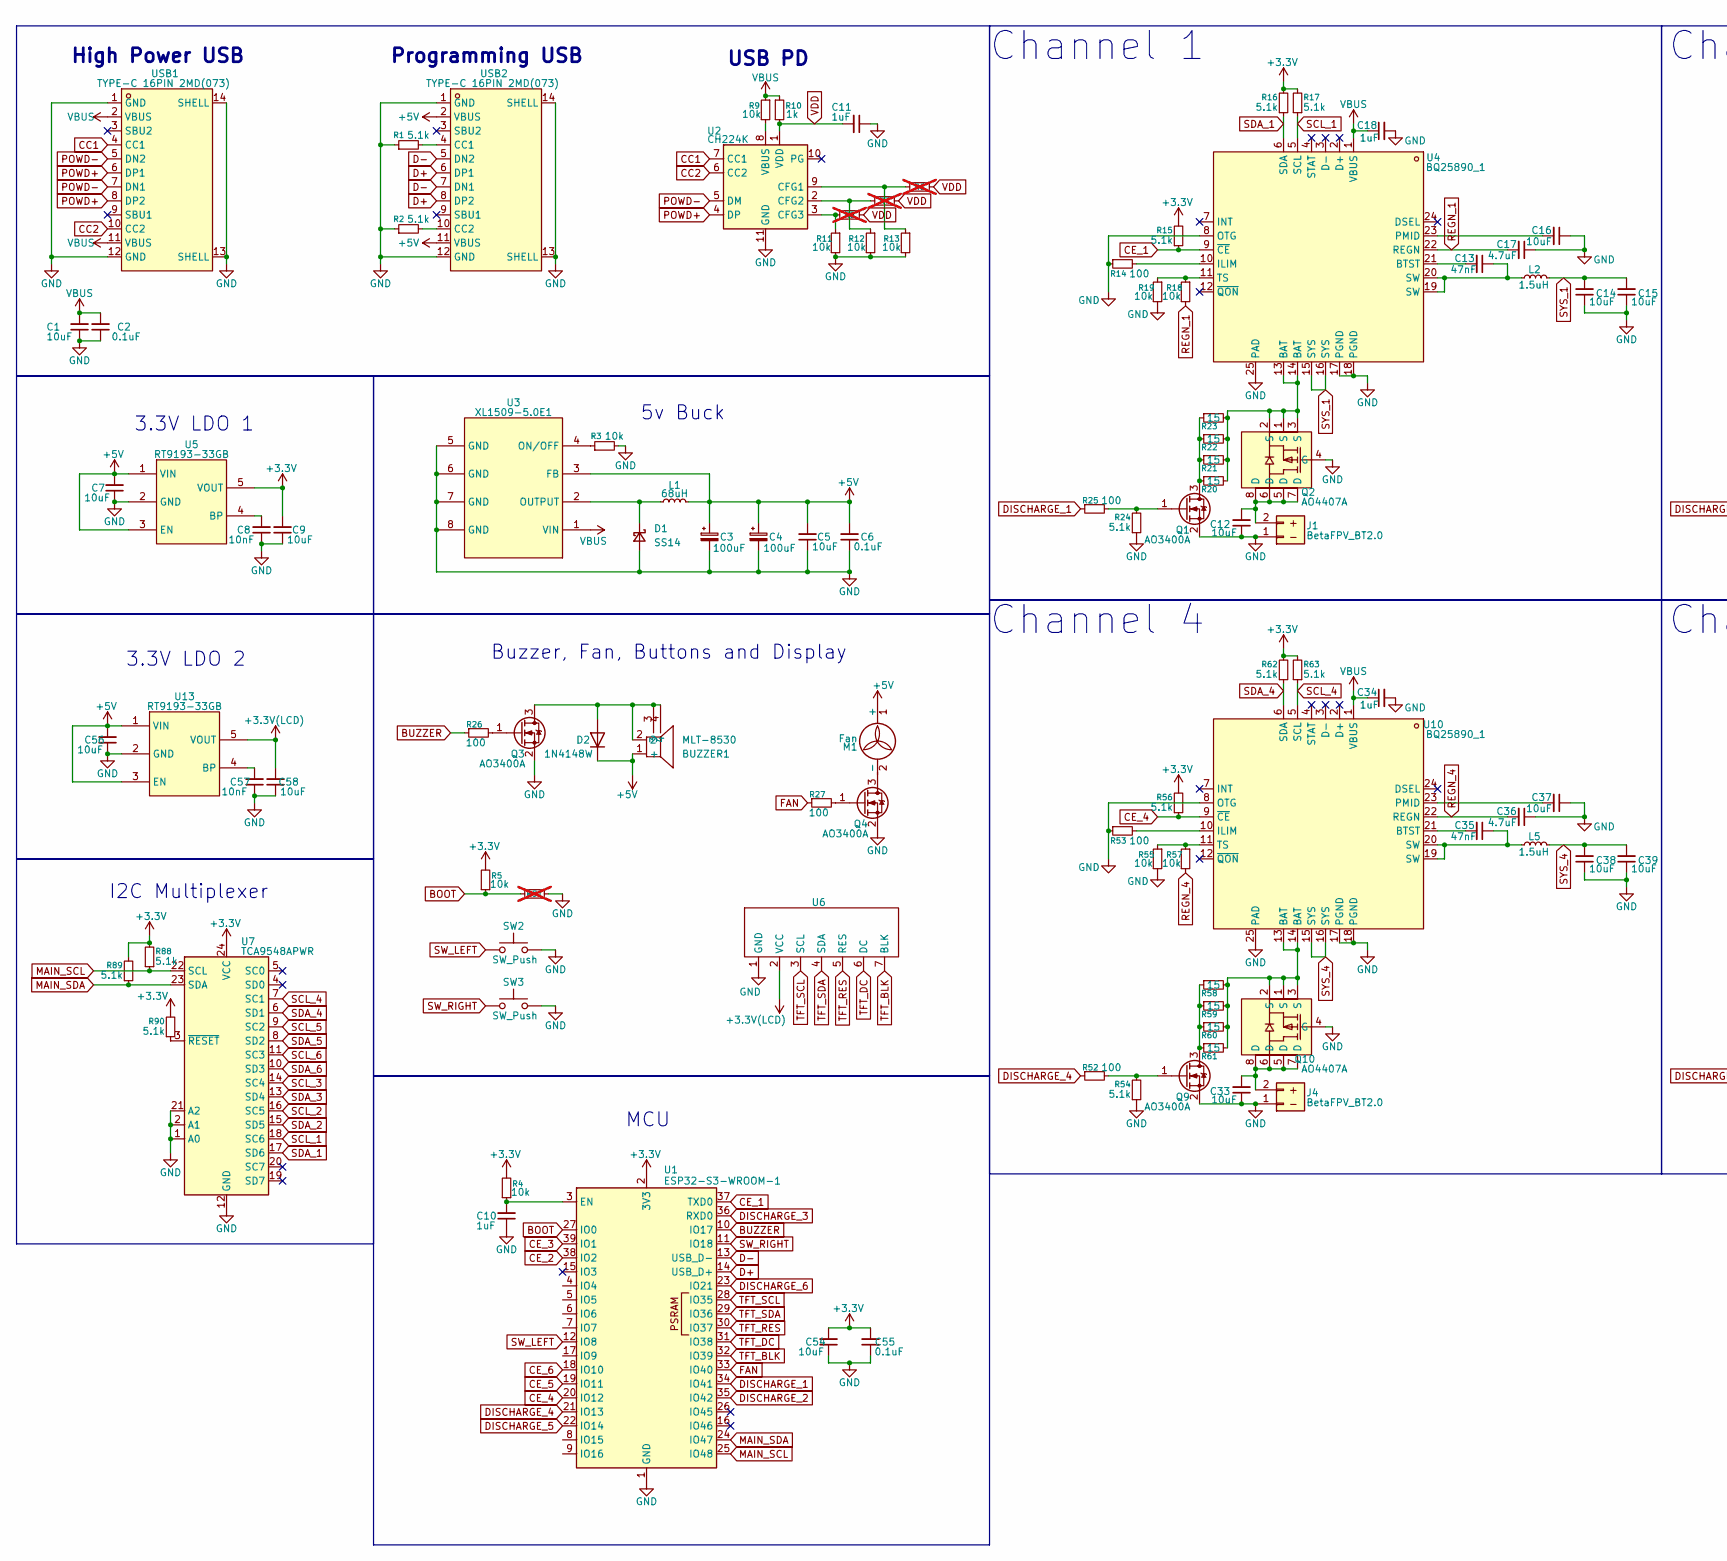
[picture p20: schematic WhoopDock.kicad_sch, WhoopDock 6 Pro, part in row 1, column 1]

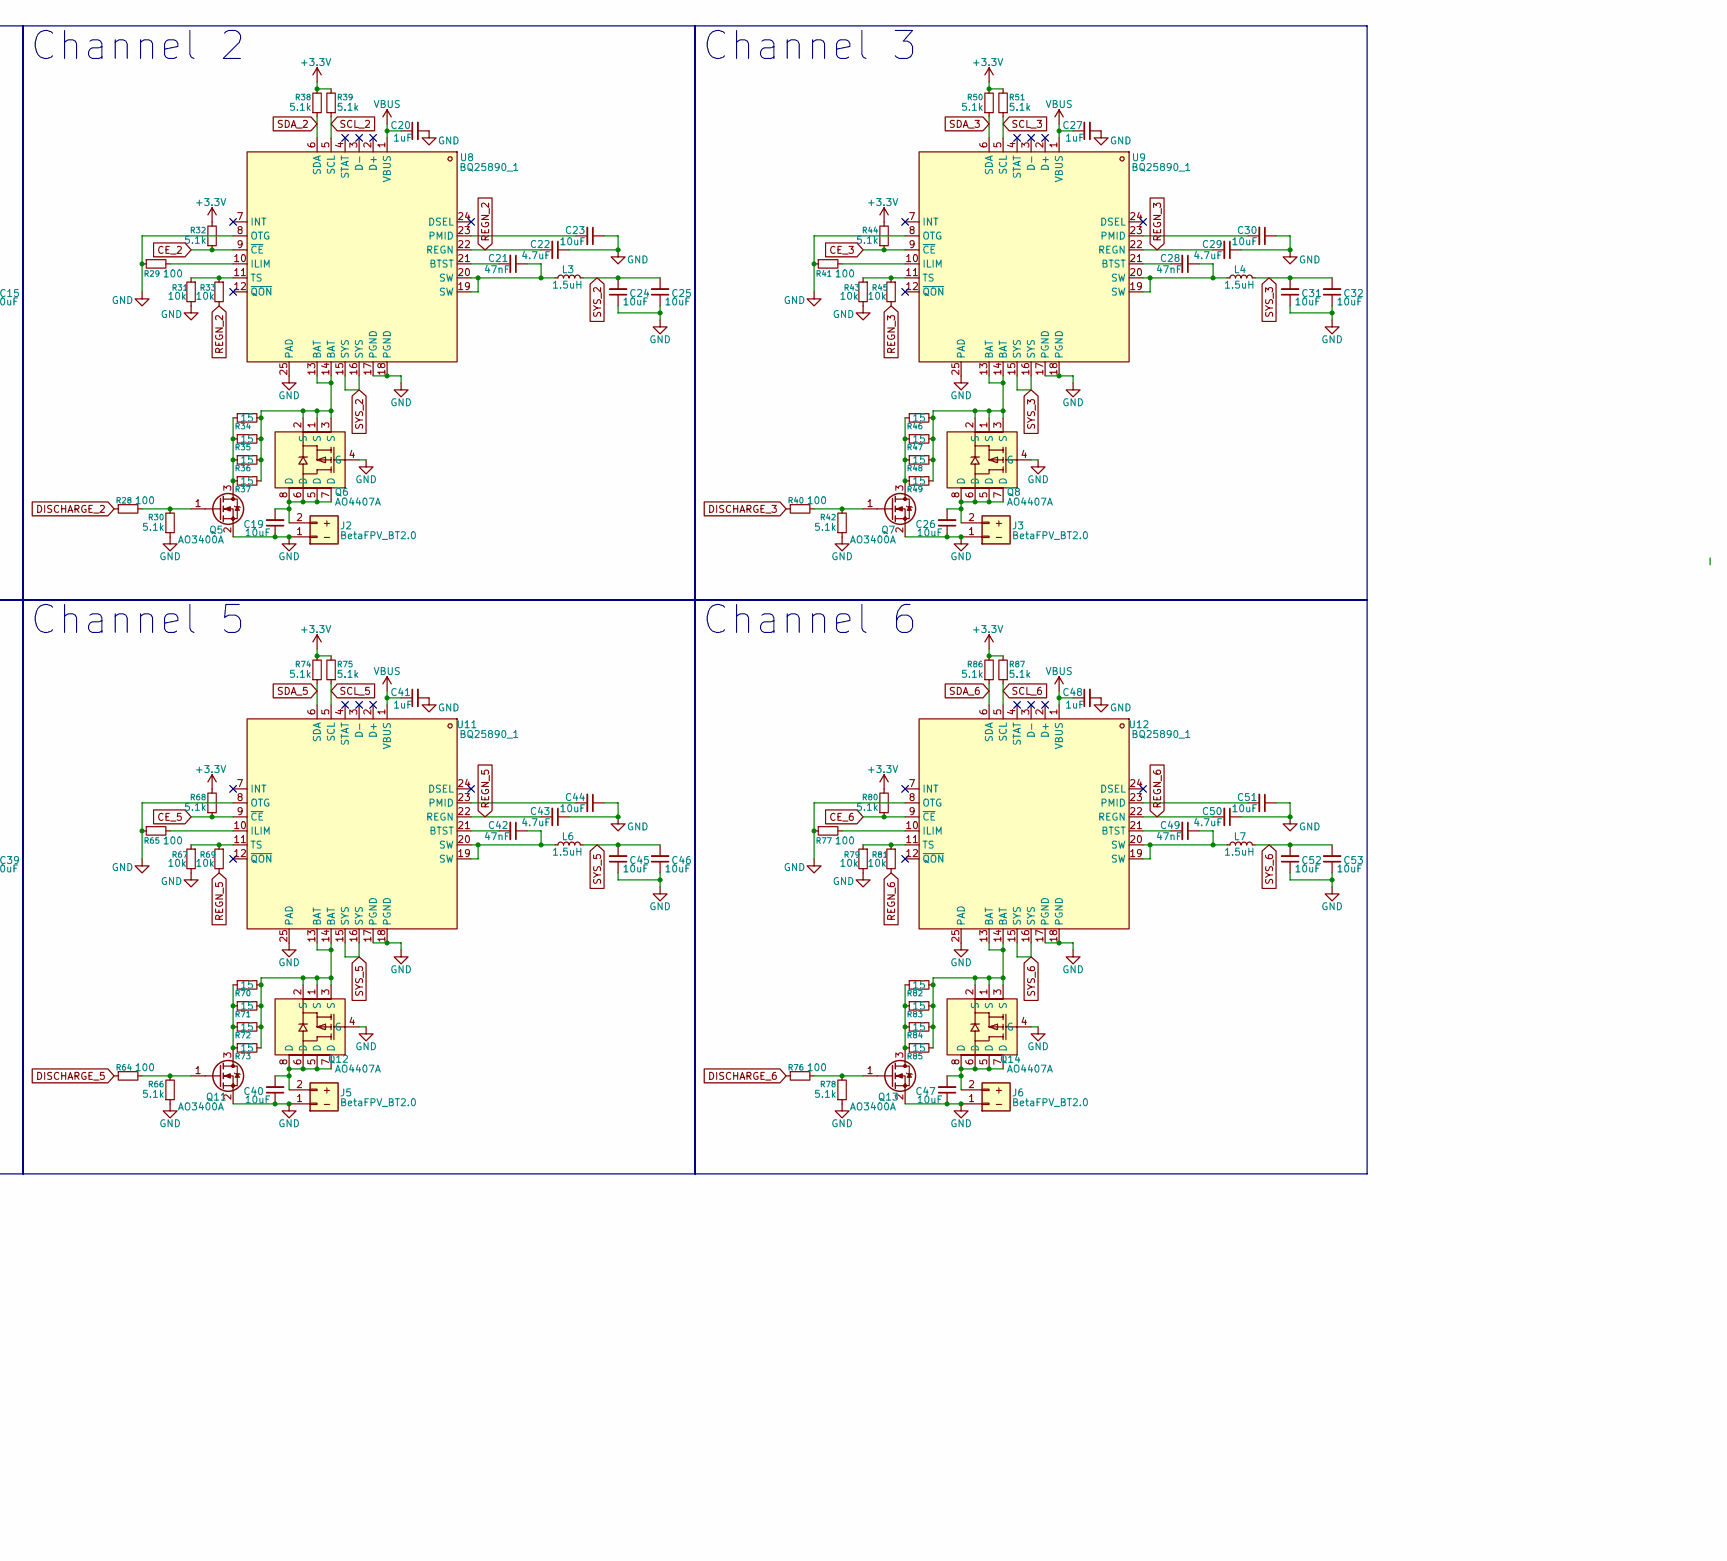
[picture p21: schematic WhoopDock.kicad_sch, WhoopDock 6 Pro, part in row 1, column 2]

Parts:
BUZZER1: MLT-8530; BUZ-SMD_4P-L8.5-W8.5-P8.50-BR; MPN MLT-8530; LCSC Part C94599
C1, C5, C7, C9, C12, C14, C15, C16, C19, C23, C24, C25, C26, C30, C31, C32, C33, C37, C38, C39, C40, C44, C45, C46, C47, C51, C52, C53, C54, C56, C58: 10uF; C_0805_2012Metric; LCSC Part C440198
C2, C6, C55: 0.1uF; C_0603_1608Metric; LCSC Part C14663
C3, C4: 100uF; CP_EIA-3216-18_Kemet-A; LCSC Part C561794
C8, C57: 10nF; C_0603_1608Metric; LCSC Part C57112
C10, C11, C18, C20, C27, C34, C41, C48: 1uF; C_0603_1608Metric; LCSC Part C15849
C13, C21, C28, C35, C42, C49: 47nF; C_0603_1608Metric; LCSC Part C1622
C17, C22, C29, C36, C43, C50: 4.7uF; C_0603_1608Metric; LCSC Part C19666
D1: SS14; D_SMA; LCSC Part C2480
D2: 1N4148W; D_SOD-123F; LCSC Part C108804
J1, J2, J3, J4, J5, J6: BetaFPV_BT2.0; BetaFPV BT2.0
L1: 68uH; L_Sunlord_SWPA8040S; LCSC Part C2894721
L2, L3, L4, L5, L6, L7: 1.5uH; L_APV_APH0420; LCSC Part C167205
M1: Fan
Q1, Q3, Q4, Q5, Q7, Q9, Q11, Q13: AO3400A; SOT-23; LCSC Part C20917
Q2, Q6, Q8, Q10, Q12, Q14: AO4407A; SOIC-8_L4.9-W3.9-P1.27-LS6.0-BL; MPN AO4407A; LCSC Part C16072
R1, R2, R15, R16, R17, R24, R30, R32, R38, R39, R42, R44, R50, R51, R54, R56, R62, R63, R66, R68, R74, R75, R78, R80, R86, R87, R88, R89, R90: 5.1k; R_0603_1608Metric; LCSC Part C23186
R3, R4, R5, R9, R11, R12, R13, R18, R19, R31, R33, R43, R45, R55, R57, R67, R69, R79, R81: 10k; R_0603_1608Metric; LCSC Part C25804
R6, R7, R8, R91: 0; R_0603_1608Metric; not fitted
R10: 1k; R_0603_1608Metric; LCSC Part C21190
R14, R25, R26, R27, R28, R29, R40, R41, R52, R53, R64, R65, R76, R77: 100; R_0603_1608Metric; LCSC Part C22775
R20, R21, R22, R23, R34, R35, R36, R37, R46, R47, R48, R49, R58, R59, R60, R61, R70, R71, R72, R73, R82, R83, R84, R85: 15; R_2512_6332Metric; LCSC Part C20087
SW2, SW3: SW_Push; SW_PUSH_6mm_H5mm; LCSC Part C2837531
U1: ESP32-S3-WROOM-1; LCSC Part C2913198
U2: CH224K; SSOP-10-1EP_3.9x4.9mm_P1mm_EP2.1x3.3mm; LCSC Part C970725
U3: XL1509-5.0E1; SOIC-8_L5.0-W4.0-P1.27-LS6.0-BL; MPN XL1509-5.0E1; LCSC Part C61063
U4, U8, U9, U10, U11, U12: BQ25890_1; WQFN-24_L4.0-W4.0-P0.50-BL-EP; MPN BQ25890RTWR; LCSC Part C130451
U5, U13: RT9193-33GB; SOT-23-5_L3.0-W1.7-P0.95-LS2.8-BL; MPN RT9193-33GB; LCSC Part C15651
U6: 1.3 TFT
U7: TCA9548APWR; TSSOP-24_4.4x7.8mm_P0.65mm; LCSC Part C130026
USB1, USB2: TYPE-C 16PIN 2MD(073); USB-C-SMD_TYPE-C-6PIN-2MD-073; LCSC Part C2765186

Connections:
+3.3V: C9.2, C54.2, C55.2, R4.2, R5.2, R15.2, R16.2, R17.2, R32.2, R38.2, R39.2, R44.2, R50.2, R51.2, R56.2, R62.2, R63.2, R68.2, R74.2, R75.2, R80.2, R86.2, R87.2, R88.2, R89.2, R90.2, U1.2 (3V3), U5.5 (VOUT), U7.24 (VCC)
+3.3V(LCD): C58.2, U6.2 (VCC), U13.5 (VOUT)
+5V: BUZZER1.1 (+), C3.1, C4.1, C5.2, C6.2, C7.2, C56.2, D2.1 (K), L1.2, M1.1 (+), U3.3 (FB), U5.1 (VIN), U5.3 (EN), U13.1 (VIN), U13.3 (EN), USB2.2 (VBUS), USB2.11 (VBUS)
BOOT: R5.1, R91.1, U1.27 (IO0)
BUZZER: R26.1, U1.10 (IO17)
CC1: U2.7 (CC1), USB1.4 (CC1)
CC2: U2.6 (CC2), USB1.10 (CC2)
CE_1: R15.1, U1.37 (TXD0), U4.9 (~CE)
CE_2: R32.1, U1.38 (IO2), U8.9 (~CE)
CE_3: R44.1, U1.39 (IO1), U9.9 (~CE)
CE_4: R56.1, U1.20 (IO12), U10.9 (~CE)
CE_5: R68.1, U1.19 (IO11), U11.9 (~CE)
CE_6: R80.1, U1.18 (IO10), U12.9 (~CE)
D+: U1.14 (USB_D+), USB2.6 (DP1), USB2.8 (DP2)
D-: U1.13 (USB_D-), USB2.5 (DN2), USB2.7 (DN1)
DISCHARGE_1: R25.1, U1.34 (IO41)
DISCHARGE_2: R28.1, U1.35 (IO42)
DISCHARGE_3: R40.1, U1.36 (RXD0)
DISCHARGE_4: R52.1, U1.21 (IO13)
DISCHARGE_5: R64.1, U1.22 (IO14)
DISCHARGE_6: R76.1, U1.23 (IO21)
FAN: R27.1, U1.33 (IO40)
GND: C1.1, C2.1, C3.2, C4.2, C5.1, C6.1, C7.1, C8.1, C9.1, C10.1, C11.1, C12.1, C14.1, C15.1, C16.1, C17.1, C18.2, C19.1, C20.2, C22.1, C23.1, C24.1, C25.1, C26.1, C27.2, C29.1, C30.1, C31.1, C32.1, C33.1, C34.2, C36.1, C37.1, C38.1, C39.1, C40.1, C41.2, C43.1, C44.1, C45.1, C46.1, C47.1, C48.2, C50.1, C51.1, C52.1, C53.1, C54.1, C55.1, C56.1, C57.1, C58.1, D1.2 (A), J1.1, J2.1, J3.1, J4.1, J5.1, J6.1, Q1.2 (S), Q2.4 (G), Q3.2 (S), Q4.2 (S), Q5.2 (S), Q6.4 (G), Q7.2 (S), Q8.4 (G), Q9.2 (S), Q10.4 (G), Q11.2 (S), Q12.4 (G), Q13.2 (S), Q14.4 (G), R1.1, R2.1, R3.2, R11.2, R12.2, R13.2, R14.1, R19.2, R24.1, R29.1, R30.1, R31.2, R41.1, R42.1, R43.2, R53.1, R54.1, R55.2, R65.1, R66.1, R67.2, R77.1, R78.1, R79.2, R91.2, SW2.2, SW3.2, U1.1 (GND), U1.40 (GND), U1.41 (GND), U2.11 (GND), U3.5 (GND), U3.6 (GND), U3.7 (GND), U3.8 (GND), U4.8 (OTG), U4.17 (PGND), U4.18 (PGND), U4.25 (PAD), U5.2 (GND), U6.1 (GND), U7.1 (A0), U7.2 (A1), U7.12 (GND), U7.21 (A2), U8.8 (OTG), U8.17 (PGND), U8.18 (PGND), U8.25 (PAD), U9.8 (OTG), U9.17 (PGND), U9.18 (PGND), U9.25 (PAD), U10.8 (OTG), U10.17 (PGND), U10.18 (PGND), U10.25 (PAD), U11.8 (OTG), U11.17 (PGND), U11.18 (PGND), U11.25 (PAD), U12.8 (OTG), U12.17 (PGND), U12.18 (PGND), U12.25 (PAD), U13.2 (GND), USB1.1 (GND), USB1.12 (GND), USB1.13 (SHELL), USB1.14 (SHELL), USB2.1 (GND), USB2.12 (GND), USB2.13 (SHELL), USB2.14 (SHELL)
MAIN_SCL: R88.1, U1.25 (IO48), U7.22 (SCL)
MAIN_SDA: R89.1, U1.24 (IO47), U7.23 (SDA)
unnamed: C13.1, L2.1, U4.19 (SW), U4.20 (SW)
unnamed: C21.1, L3.1, U8.19 (SW), U8.20 (SW)
unnamed: C28.1, L4.1, U9.19 (SW), U9.20 (SW)
unnamed: C35.1, L5.1, U10.19 (SW), U10.20 (SW)
unnamed: C42.1, L6.1, U11.19 (SW), U11.20 (SW)
unnamed: C49.1, L7.1, U12.19 (SW), U12.20 (SW)
unnamed: D1.1 (K), L1.1, U3.2 (OUTPUT)
unnamed: BUZZER1.2, BUZZER1.3, BUZZER1.4, D2.2 (A), Q3.3 (D)
unnamed: C12.2, J1.2, Q2.5 (D), Q2.6 (D), Q2.7 (D), Q2.8 (D)
unnamed: C19.2, J2.2, Q6.5 (D), Q6.6 (D), Q6.7 (D), Q6.8 (D)
unnamed: C26.2, J3.2, Q8.5 (D), Q8.6 (D), Q8.7 (D), Q8.8 (D)
unnamed: C33.2, J4.2, Q10.5 (D), Q10.6 (D), Q10.7 (D), Q10.8 (D)
unnamed: C40.2, J5.2, Q12.5 (D), Q12.6 (D), Q12.7 (D), Q12.8 (D)
unnamed: C47.2, J6.2, Q14.5 (D), Q14.6 (D), Q14.7 (D), Q14.8 (D)
unnamed: M1.2 (-), Q4.3 (D)
unnamed: Q1.3 (D), R20.1, R21.1, R22.1, R23.1
unnamed: Q1.1 (G), R24.2, R25.2
unnamed: Q2.1 (S), Q2.2 (S), Q2.3 (S), R20.2, R21.2, R22.2, R23.2, U4.13 (BAT), U4.14 (BAT)
unnamed: Q3.1 (G), R26.2
unnamed: Q4.1 (G), R27.2
unnamed: Q5.3 (D), R34.1, R35.1, R36.1, R37.1
unnamed: Q5.1 (G), R28.2, R30.2
unnamed: Q6.1 (S), Q6.2 (S), Q6.3 (S), R34.2, R35.2, R36.2, R37.2, U8.13 (BAT), U8.14 (BAT)
unnamed: Q7.3 (D), R46.1, R47.1, R48.1, R49.1
unnamed: Q7.1 (G), R40.2, R42.2
unnamed: Q8.1 (S), Q8.2 (S), Q8.3 (S), R46.2, R47.2, R48.2, R49.2, U9.13 (BAT), U9.14 (BAT)
unnamed: Q9.3 (D), R58.1, R59.1, R60.1, R61.1
unnamed: Q9.1 (G), R52.2, R54.2
unnamed: Q10.1 (S), Q10.2 (S), Q10.3 (S), R58.2, R59.2, R60.2, R61.2, U10.13 (BAT), U10.14 (BAT)
unnamed: Q11.3 (D), R70.1, R71.1, R72.1, R73.1
unnamed: Q11.1 (G), R64.2, R66.2
unnamed: Q12.1 (S), Q12.2 (S), Q12.3 (S), R70.2, R71.2, R72.2, R73.2, U11.13 (BAT), U11.14 (BAT)
unnamed: Q13.3 (D), R82.1, R83.1, R84.1, R85.1
unnamed: Q13.1 (G), R76.2, R78.2
unnamed: Q14.1 (S), Q14.2 (S), Q14.3 (S), R82.2, R83.2, R84.2, R85.2, U12.13 (BAT), U12.14 (BAT)
unnamed: C10.2, R4.1, U1.3 (EN)
unnamed: R6.1, R13.1, U2.9 (CFG1)
unnamed: R7.1, R12.1, U2.2 (CFG2)
unnamed: R8.1, R11.1, U2.3 (CFG3)
unnamed: R9.2, U2.8 (VBUS)
unnamed: R3.1, U3.4 (ON/OFF)
unnamed: C13.2, U4.21 (BTST)
unnamed: R14.2, U4.10 (ILIM)
unnamed: C16.2, U4.23 (PMID)
unnamed: R18.1, R19.1, U4.11 (TS)
unnamed: C8.2, U5.4 (BP)
unnamed: R90.1, U7.3 (~RESET)
unnamed: C21.2, U8.21 (BTST)
unnamed: R29.2, U8.10 (ILIM)
unnamed: C23.2, U8.23 (PMID)
unnamed: R31.1, R33.1, U8.11 (TS)
unnamed: C28.2, U9.21 (BTST)
unnamed: R41.2, U9.10 (ILIM)
unnamed: C30.2, U9.23 (PMID)
unnamed: R43.1, R45.1, U9.11 (TS)
unnamed: C35.2, U10.21 (BTST)
unnamed: R53.2, U10.10 (ILIM)
unnamed: C37.2, U10.23 (PMID)
unnamed: R55.1, R57.1, U10.11 (TS)
unnamed: C42.2, U11.21 (BTST)
unnamed: R65.2, U11.10 (ILIM)
unnamed: C44.2, U11.23 (PMID)
unnamed: R67.1, R69.1, U11.11 (TS)
unnamed: C49.2, U12.21 (BTST)
unnamed: R77.2, U12.10 (ILIM)
unnamed: C51.2, U12.23 (PMID)
unnamed: R79.1, R81.1, U12.11 (TS)
unnamed: C57.2, U13.4 (BP)
unnamed: R1.2, USB2.4 (CC1)
unnamed: R2.2, USB2.10 (CC2)
POWD+: U2.4 (DP), USB1.6 (DP1), USB1.8 (DP2)
POWD-: U2.5 (DM), USB1.5 (DN2), USB1.7 (DN1)
REGN_1: C17.2, R18.2, U4.22 (REGN)
REGN_2: C22.2, R33.2, U8.22 (REGN)
REGN_3: C29.2, R45.2, U9.22 (REGN)
REGN_4: C36.2, R57.2, U10.22 (REGN)
REGN_5: C43.2, R69.2, U11.22 (REGN)
REGN_6: C50.2, R81.2, U12.22 (REGN)
SCL_1: R17.1, U4.5 (SCL), U7.18 (SC6)
SCL_2: R39.1, U7.16 (SC5), U8.5 (SCL)
SCL_3: R51.1, U7.14 (SC4), U9.5 (SCL)
SCL_4: R63.1, U7.7 (SC1), U10.5 (SCL)
SCL_5: R75.1, U7.9 (SC2), U11.5 (SCL)
SCL_6: R87.1, U7.11 (SC3), U12.5 (SCL)
SDA_1: R16.1, U4.6 (SDA), U7.17 (SD6)
SDA_2: R38.1, U7.15 (SD5), U8.6 (SDA)
SDA_3: R50.1, U7.13 (SD4), U9.6 (SDA)
SDA_4: R62.1, U7.6 (SD1), U10.6 (SDA)
SDA_5: R74.1, U7.8 (SD2), U11.6 (SDA)
SDA_6: R86.1, U7.10 (SD3), U12.6 (SDA)
SW_LEFT: SW2.1, U1.12 (IO8)
SW_RIGHT: SW3.1, U1.11 (IO18)
SYS_1: C14.2, C15.2, L2.2, U4.15 (SYS), U4.16 (SYS)
SYS_2: C24.2, C25.2, L3.2, U8.15 (SYS), U8.16 (SYS)
SYS_3: C31.2, C32.2, L4.2, U9.15 (SYS), U9.16 (SYS)
SYS_4: C38.2, C39.2, L5.2, U10.15 (SYS), U10.16 (SYS)
SYS_5: C45.2, C46.2, L6.2, U11.15 (SYS), U11.16 (SYS)
SYS_6: C52.2, C53.2, L7.2, U12.15 (SYS), U12.16 (SYS)
TFT_BLK: U1.32 (IO39), U6.7 (BLK)
TFT_DC: U1.31 (IO38), U6.6 (DC)
TFT_RES: U1.30 (IO37), U6.5 (RES)
TFT_SCL: U1.28 (IO35), U6.3 (SCL)
TFT_SDA: U1.29 (IO36), U6.4 (SDA)
VBUS: C1.2, C2.2, C18.1, C20.1, C27.1, C34.1, C41.1, C48.1, R9.1, R10.1, U3.1 (VIN), U4.1 (VBUS), U8.1 (VBUS), U9.1 (VBUS), U10.1 (VBUS), U11.1 (VBUS), U12.1 (VBUS), USB1.2 (VBUS), USB1.11 (VBUS)
VDD: C11.2, R6.2, R7.2, R8.2, R10.2, U2.1 (VDD)

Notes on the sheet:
High Power USB
3.3V LDO 1
USB PD
Channel 1
5v Buck
Buzzer, Fan, Buttons and Display
Channel 3
3.3V LDO 2
I2C Multiplexer
Channel 5
Channel 6
Channel 2
Programming USB
Channel 4
MCU

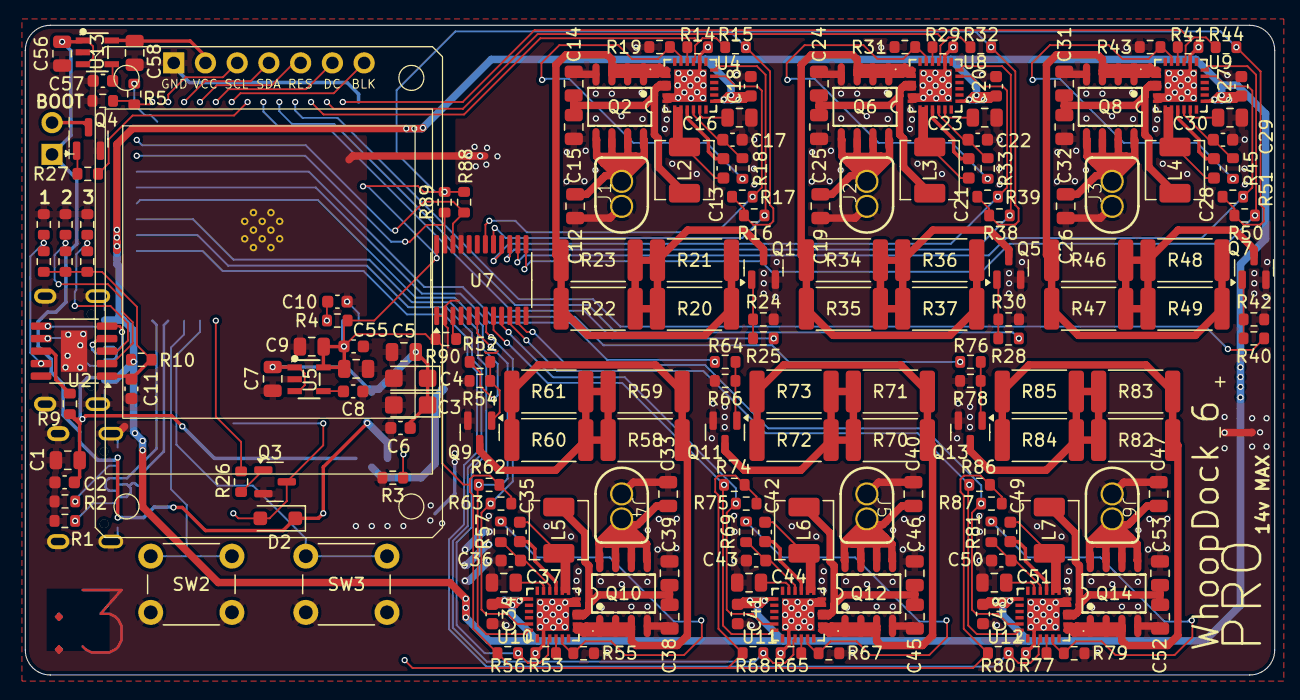
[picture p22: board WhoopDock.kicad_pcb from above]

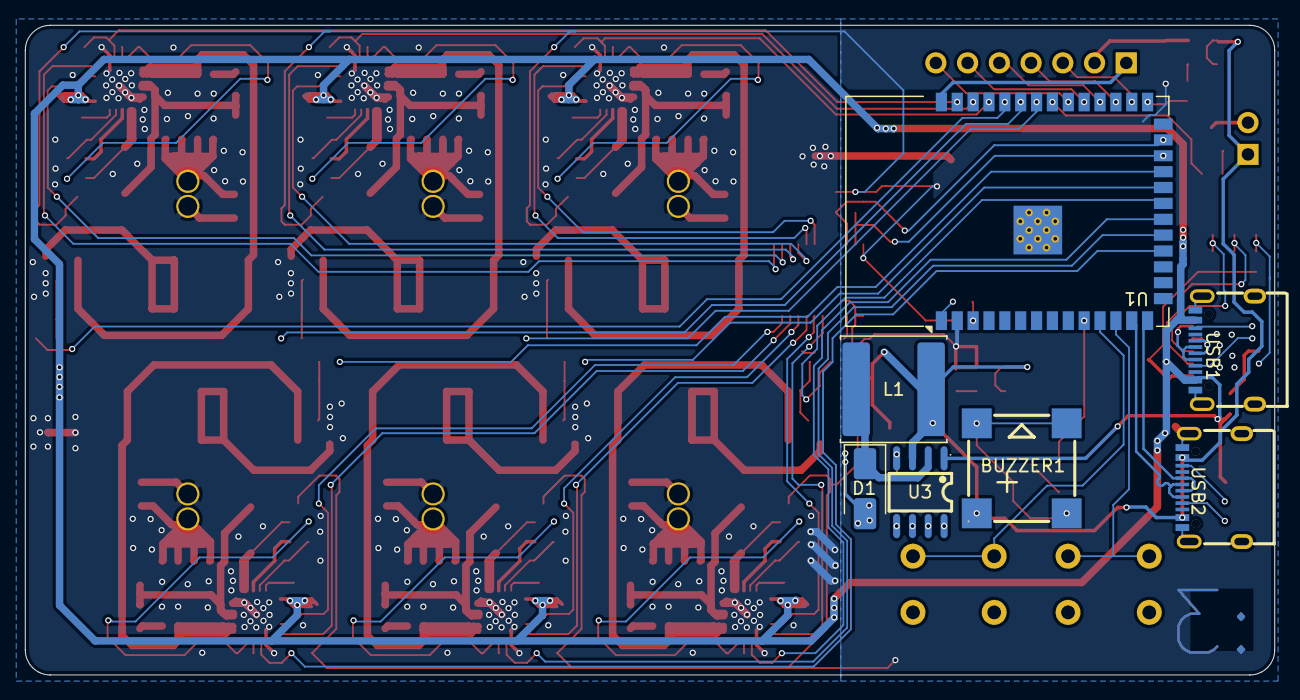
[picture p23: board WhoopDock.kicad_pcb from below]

Board: 2 copper layers, 100.0 x 52.0 mm, 197 parts (7 on the bottom side), 130 nets.

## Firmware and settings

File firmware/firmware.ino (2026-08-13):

// Generated by Gemini
#include <Wire.h>
#include <SPI.h>
#include <Adafruit_GFX.h>
#include <Adafruit_ST7789.h>

// ==========================================
// PIN DEFINITIONS
// ==========================================

// --- TFT Screen (1.3" 240x240 ST7789) ---
// Note: CS pin is assumed grounded/absent on this module
#define TFT_SCL 35 // SPI SCK
#define TFT_SDA 36 // SPI MOSI
#define TFT_RES 37 // Reset
#define TFT_DC  38 // Data/Command
#define TFT_BLK 39 // Backlight

// --- I2C & Multiplexer ---
#define I2C_SDA 47
#define I2C_SCL 48
#define TCA_ADDR 0x70
#define BQ25890_ADDR 0x6A // Default I2C address for BQ25890

// --- Fan & Buzzer (PWM) ---
#define FAN_PIN 40
#define BUZZER_PIN 17

// --- Buttons ---
#define BTN_LEFT 8
#define BTN_RIGHT 18

// --- Channel Arrays (1 to 6) ---
// ESP32-S3 Defaults: RXD0 is GPIO44, TXD0 is GPIO43
const uint8_t DISCHARGE_PINS[6] = {41, 42, 44, 13, 14, 21};
const uint8_t CE_PINS[6]        = {43, 2, 1, 12, 11, 10};

// TCA9548A Ports mapped to Channels 1-6: S6, S5, S4, S1, S2, S3
const uint8_t TCA_PORTS[6]      = {6, 5, 4, 1, 2, 3};

// Initialize TFT Display (-1 for CS since it is unused/grounded)
Adafruit_ST7789 tft = Adafruit_ST7789(-1, TFT_DC, TFT_SDA, TFT_SCL, TFT_RES);

// ==========================================
// HELPER FUNCTIONS
// ==========================================

// Switch the TCA9548A multiplexer to a specific port
void tcaSelectPort(uint8_t port) {
  if (port > 7) return;
  Wire.beginTransmission(TCA_ADDR);
  Wire.write(1 << port); 
  Wire.endTransmission();
}

// Example function: Read the system status register from BQ25890
uint8_t readBQ25890Status(uint8_t channelIndex) {
  // 1. Switch I2C Mux to the correct port for this channel
  tcaSelectPort(TCA_PORTS[channelIndex]);
  
  // 2. Request Register 0x0B (System Status Register)
  Wire.beginTransmission(BQ25890_ADDR);
  Wire.write(0x0B); 
  Wire.endTransmission(false); // Repeated start
  
  Wire.requestFrom(BQ25890_ADDR, 1);
  if (Wire.available()) {
    return Wire.read();
  }
  return 0xFF; // Return error state if nothing read
}

// ==========================================
// MAIN SETUP
// ==========================================

void setup() {
  Serial.begin(115200);
  delay(1000); // Give Serial time to initialize
  
  Serial.println("Starting Charge Controller...");

  // 1. Initialize I2C Bus (with external pullups on the multiplexer)
  Wire.begin(I2C_SDA, I2C_SCL);
  Wire.setClock(400000); // Fast I2C

  // 2. Initialize Buttons (Internal Pullups)
  pinMode(BTN_LEFT, INPUT_PULLUP);
  pinMode(BTN_RIGHT, INPUT_PULLUP);

  // 3. Initialize Fan and Buzzer
  pinMode(FAN_PIN, OUTPUT);
  pinMode(BUZZER_PIN, OUTPUT);
  analogWrite(FAN_PIN, 0);    // Turn off fan initially
  analogWrite(BUZZER_PIN, 0); // Turn off buzzer initially

  // 4. Initialize Channel Pins
  for (int i = 0; i < 6; i++) {
    // Dischargers
    pinMode(DISCHARGE_PINS[i], OUTPUT);
    analogWrite(DISCHARGE_PINS[i], 0); // 0% duty cycle (Off)

    // BQ25890 Charge Enable (CE)
    // Note: BQ25890 CE pin is usually Active LOW. High = Disabled, Low = Enabled.
    pinMode(CE_PINS[i], OUTPUT);
    digitalWrite(CE_PINS[i], HIGH); // Default to disabled for safety
  }

  // 5. Initialize TFT Display
  pinMode(TFT_BLK, OUTPUT);
  digitalWrite(TFT_BLK, HIGH); // Turn on backlight
  
  tft.init(240, 240); // Initialize standard 240x240 TFT
  tft.setRotation(2); // Adjust 0-3 depending on your screen orientation
  tft.fillScreen(ST77XX_BLACK);
  
  // Draw Initial UI
  tft.setCursor(10, 10);
  tft.setTextColor(ST77XX_WHITE);
  tft.setTextSize(2);
  tft.println("Controller Init");
  tft.println("Status: OK");
}

// ==========================================
// MAIN LOOP
// ==========================================

void loop() {
  // 1. Handle Button Inputs
  if (digitalRead(BTN_LEFT) == LOW) {
    Serial.println("Left Button Pressed");
    // Add debounce & logic here
    delay(200); 
  }
  
  if (digitalRead(BTN_RIGHT) == LOW) {
    Serial.println("Right Button Pressed");
    // Add debounce & logic here
    delay(200); 
  }

  // 2. Scan BQ25890 Statuses via Multiplexer
  // (We'll print them to Serial, but you can draw them to the TFT later)
  for (int i = 0; i < 6; i++) {
    uint8_t status = readBQ25890Status(i);
    
    // Check if communication failed
    if(status == 0xFF) {
      Serial.printf("Ch %d (Mux Port %d): BQ25890 Not Found\n", i+1, TCA_PORTS[i]);
    } else {
      // VBUS Status is bits 7:6 in reg 0x0B
      uint8_t vbusStat = (status & 0b11000000) >> 6;
      Serial.printf("Ch %d (Mux Port %d): Status Reg 0x%02X | VBUS: %d\n", i+1, TCA_PORTS[i], status, vbusStat);
    }
  }
  
  Serial.println("-------------------------");
  
  // 3. Example: Update Display dynamically
  tft.fillRect(10, 50, 220, 40, ST77XX_BLACK); // Clear previous text area
  tft.setCursor(10, 50);
  tft.setTextColor(ST77XX_GREEN);
  tft.setTextSize(2);
  tft.printf("Uptime: %lu s", millis() / 1000);

  // 4. Example: Fan Control (Sweep 0 to 255)
  // analogWrite(FAN_PIN, 128); // 50% Speed

  delay(1000); // Wait 1 second before next cycle
}

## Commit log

2026-08-11 PCB Done
    [WhoopDock.kicad_pcb, WhoopDock.kicad_sch]
2026-08-13 fixed PCB
    [WhoopDock.kicad_pcb]
2026-08-13 almost finalized except for readme
    [Buttons.stl, Feets.stl, WhoopDock.kicad_pcb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]
2026-08-13 Clarify active cooling description and BOM note
    Updated the description of active cooling and added a note about component costs.
